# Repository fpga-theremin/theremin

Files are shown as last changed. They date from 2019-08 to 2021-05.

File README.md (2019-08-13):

# FPGA based theremin

Open source digital FPGA based theremin project.

Hardware design and build instructions can be found on [FPGA Theremin Project Page](https://fpga-theremin.github.io/theremin/)

[Theremin](https://en.wikipedia.org/wiki/Theremin) is an electronic musical instrument controlled without physical contact by the thereminist (performer).
It is named after the Westernized name of its Soviet inventor, Léon Theremin (Лев Термéн), who patented the device in 1928. 

FPGA Theremin project is attempt to build modern digital theremin with rich set of features.

## License 
FPGA Theremin is open source hardware and software project.

All hardware designed for this project 
is published under [TAPR Open Hardware License](https://www.tapr.org/TAPR_Open_Hardware_License_v1.0.txt)

All software (including both HDL and C/C++ code) 
is published under [GNU GENERAL PUBLIC LICENSE Version 2](https://www.gnu.org/licenses/old-licenses/gpl-2.0.txt)

## HDL sources

Modules are written in SystemVerilog.

Some of modules use Xilinx Series 7 specific hardware blocks.

HLD code for modules:

* [theremin_sensor](https://github.com/fpga-theremin/theremin/tree/master/fpga/ip_repo/theremin_ip/src/theremin_sensor) - double channel high precision frequency meter
* [encoders_board](https://github.com/fpga-theremin/theremin/tree/master/fpga/ip_repo/theremin_ip/src/encoders_board) - interfacing to 5 incremental encoders with buttons and one tact button
* [lcd_controller](https://github.com/fpga-theremin/theremin/tree/master/fpga/ip_repo/theremin_ip/src/lcd_controller) - LCD controller with RGB interface and DMA
* [audio_io](https://github.com/fpga-theremin/theremin/tree/master/fpga/ip_repo/theremin_ip/src/audio_io) - audio out 2 * stereo * 24bit * 48KHz I2S outputs and one stereo * 24bit * 48KHz I2S input
* [theremin_i2c](https://github.com/fpga-theremin/theremin/tree/master/fpga/ip_repo/theremin_ip/src/theremin_i2c) - I2C support
* [theremin_io](https://github.com/fpga-theremin/theremin/tree/master/fpga/ip_repo/theremin_ip/src/theremin_io) - Top Level Module combining all theremin peripherials

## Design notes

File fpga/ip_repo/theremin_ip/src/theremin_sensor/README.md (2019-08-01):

# Theremin Sensor module

Pitch and Volume oscillators produce 3.3V digital signal with frequency in range 200KHz..2MHz depending on inductor, duty cycle 50% (for implementation with flip-flop output).

Two input pins of FPGA board are used for receiving oscillator signals.

Frequency varies by ~7% depending on hand distance to antenna.

It's necessary to measure frequency of both signals with highest possible precision.

We can track changes of input signal and count number of clock cycles between its edges. Straightforward implementation in FPGA with counter may only provide limited resolution. 
200-300MHz is maximum possible resolution for simple counter based solution.

More sofisticated approach is required to get better precision.

There is a hardware deserielizer primitive in Xilinx Series 7 FPGAs.

ISERDESE2 in DDR mode allows to pack 8 sequencial samples of serial signal into parallel 8 bit output.

Max base frequency of ISERDESE2 on Cora Z7 device is 600MHz. In DDR mode, it samples input with 600MHz * 2 = 1.2GHz rate and provides new output each 600MHz / 4 = 150MHz clock cycle.

Parallel output of deserializer may be processed with lower frequency (150MHz) still providing 1.2GHz resolution.

This design still can be improved using Oversampling technique.

Measuring of the same signal several times with different delay and then averaging may allow to increase precision. Doubling of measures gives one additional bit of signal period data.

Simple oversampling solution used in this design uses 8 ISERDESE2 primitives with IDELAYE2 primitives on their inputs. Delay values are chosen to distribute subsamples evenly inside one 1.2GHz clock cycle.
It allows to get 64 bits (samples) of deserialized data each 150MHz clock cycle instead of 8 samples available with single ISERDESE2 deserializer.
Oversampling effectively gives 1.2GHz * 8 = 9.6GHz precision.

Once we have 64 bits of parallel data, we need to process them to measure intervals between sequential signal edges.

Steps of oversampling frequency measure processing:

* Deserialize input signal into 64 bits (samples) once per 150MHz cycle.
* Convert 64 bit values into single bit change flag and 6 bit changed bit number (0..63)
* Track changes to accumulate duration between signal edges - gives half period value (since last change, for either 0 or 1 signal value).
* Add two last half-period values to get full period value (number of 9.6GHz samples the same edge - positive or negative, new value is available after each input change).
* Filter measured period value using 4-stage IIR filter - to increase number of available bits

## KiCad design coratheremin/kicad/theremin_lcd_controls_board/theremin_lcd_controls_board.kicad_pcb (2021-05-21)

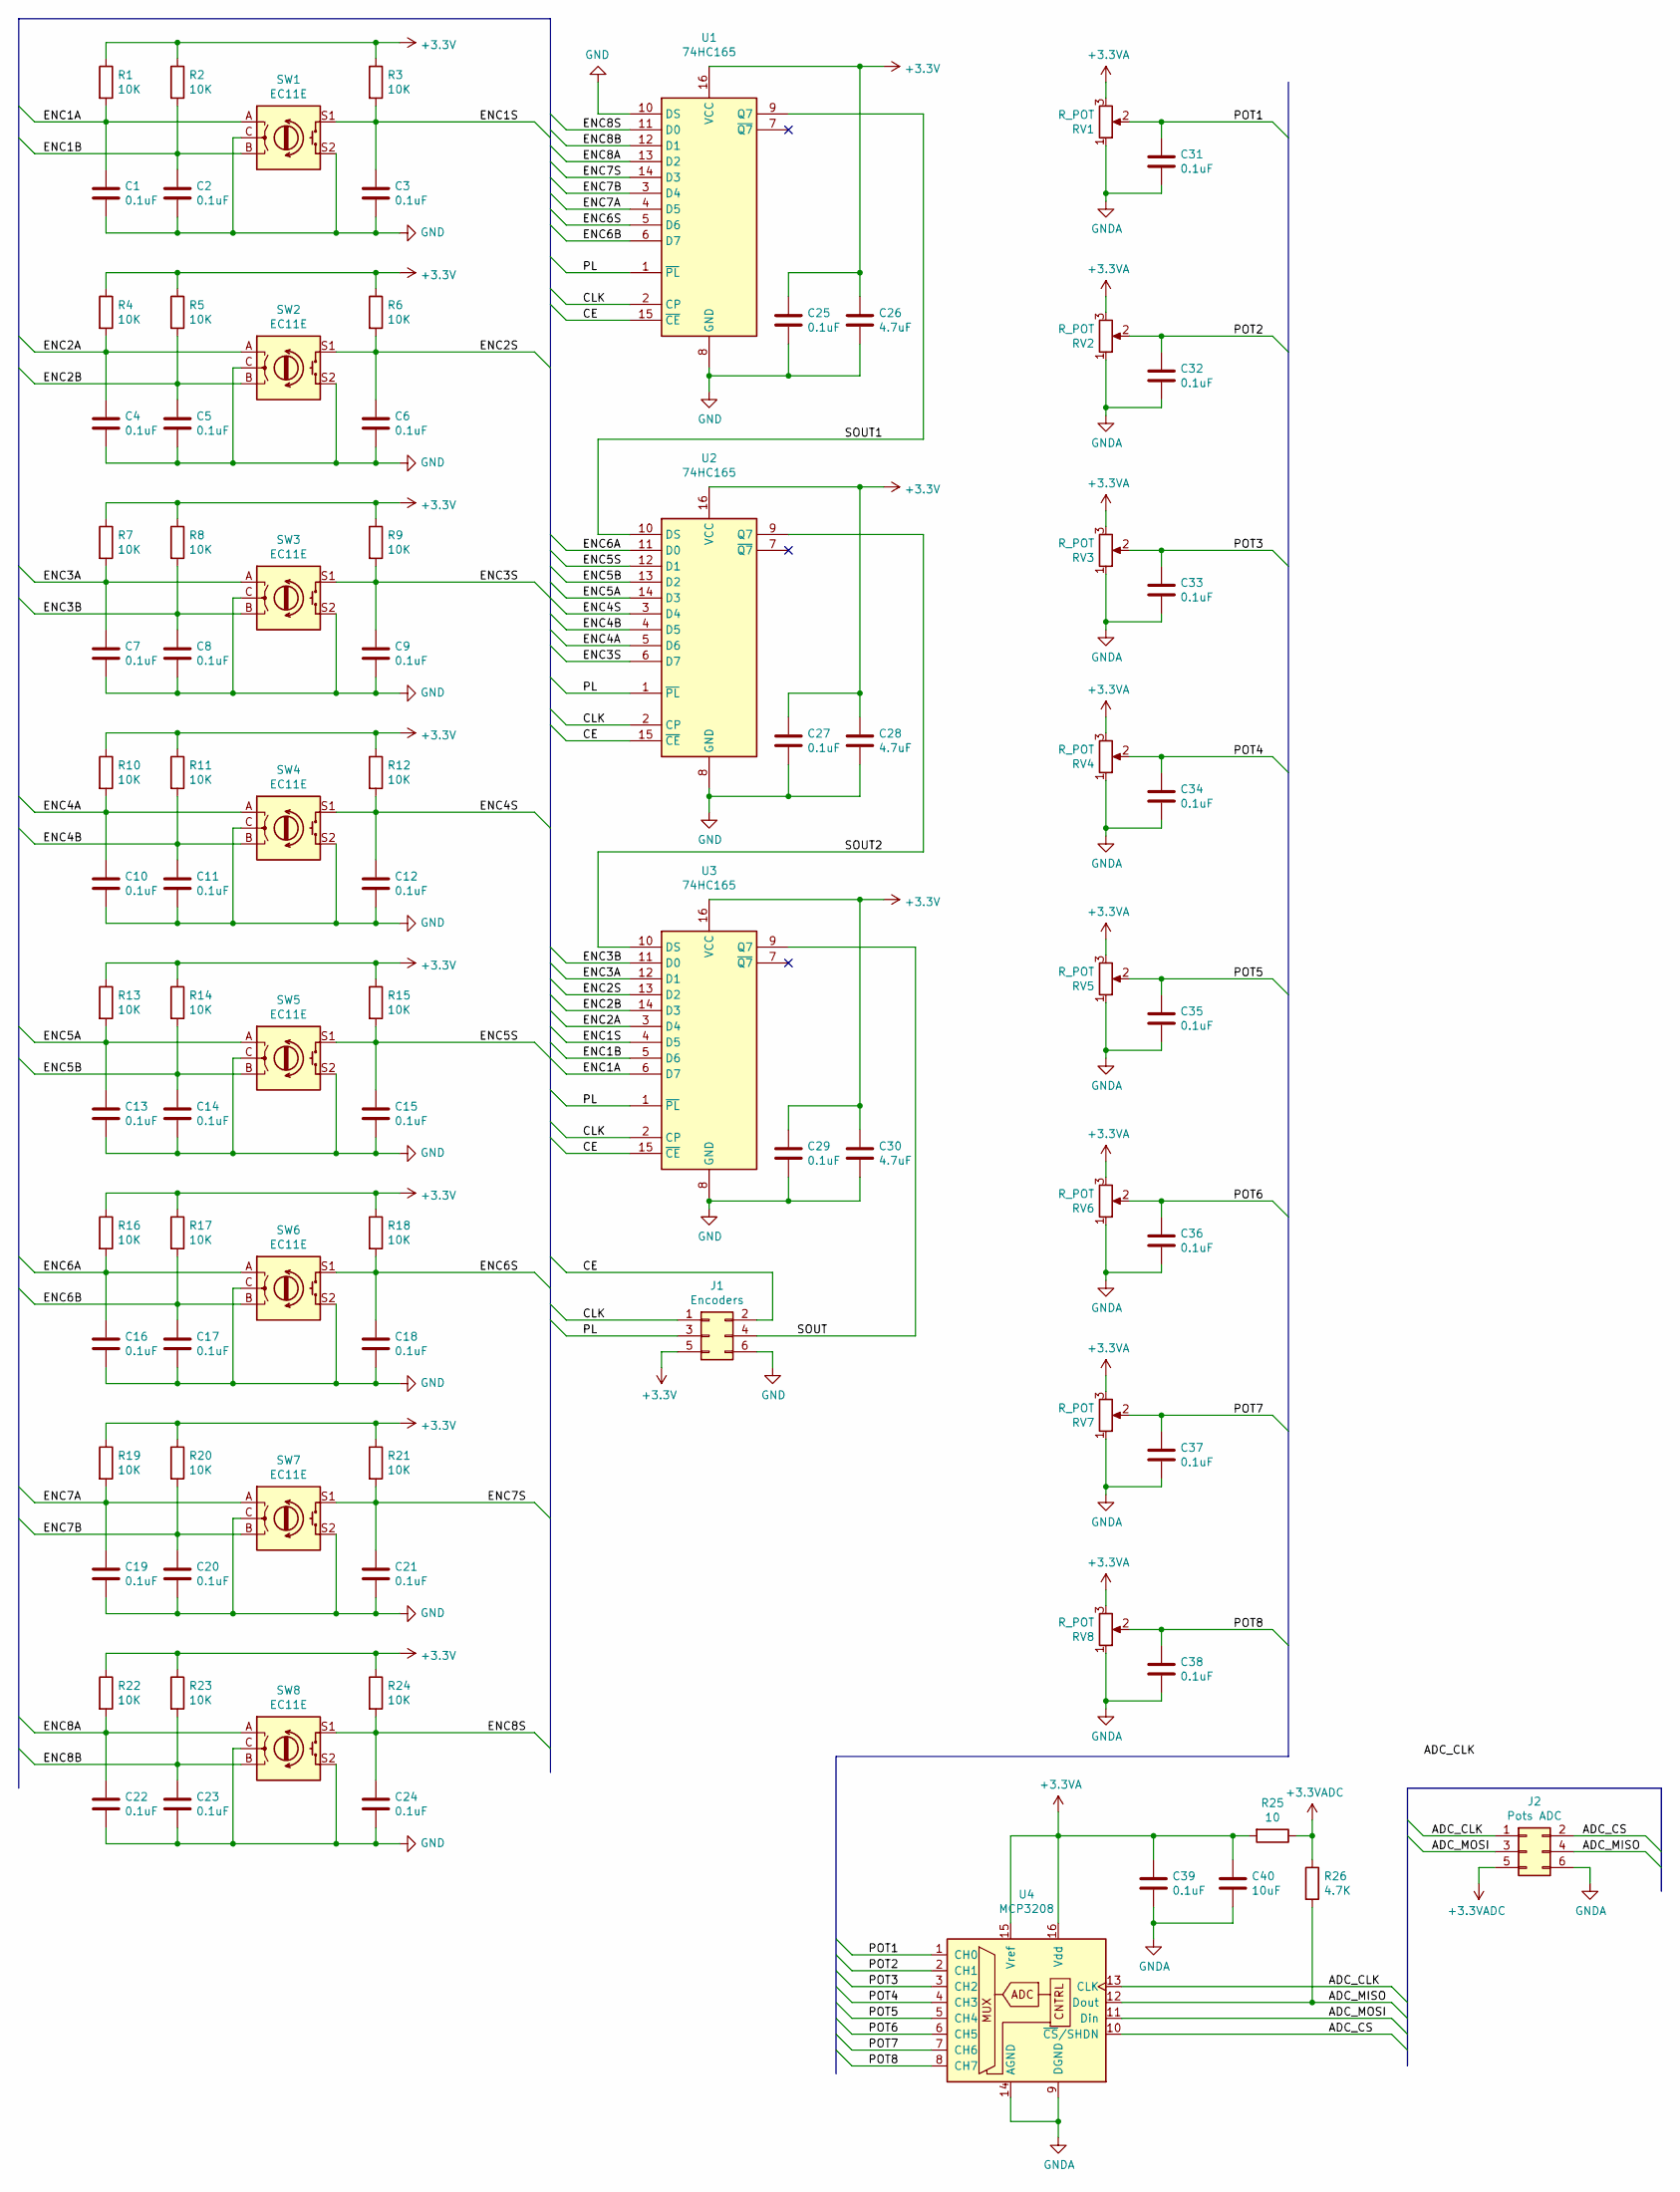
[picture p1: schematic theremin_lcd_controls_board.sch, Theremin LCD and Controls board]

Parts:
C1, C2, C3, C4, C5, C6, C7, C8, C9, C10, C11, C12, C13, C14, C15, C16, C17, C18, C19, C20, C21, C22, C23, C24, C25, C27, C29, C31, C32, C33, C34, C35, C36, C37, C38, C39: 0.1uF; C_0805_2012Metric
C26, C28, C30: 4.7uF; C_0805_2012Metric
C40: 10uF; C_0805_2012Metric
J1: Encoders; IDC-Header_2x03_P2.54mm_Vertical
J2: Pots ADC; IDC-Header_2x03_P2.54mm_Vertical
R1, R2, R3, R4, R5, R6, R7, R8, R9, R10, R11, R12, R13, R14, R15, R16, R17, R18, R19, R20, R21, R22, R23, R24: 10K; R_0805_2012Metric
R25: 10; R_0805_2012Metric
R26: 4.7K; R_0805_2012Metric
RV1, RV2, RV3, RV4, RV5, RV6, RV7, RV8: R_POT; Potentiometer_TT_P0915N
SW1, SW2, SW3, SW4, SW5, SW6, SW7, SW8: EC11E; RotaryEncoder_Alps_EC11E-Switch_Vertical_H20mm
U1, U2, U3: 74HC165; SO-16_3.9x9.9mm_P1.27mm
U4: MCP3208; SOIC-16_3.9x9.9mm_P1.27mm

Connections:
+3.3VA: C39.1, C40.1, R25.2, RV1.3, RV2.3, RV3.3, RV4.3, RV5.3, RV6.3, RV7.3, RV8.3, U4.15 (Vref), U4.16 (Vdd)
+3.3VADC: J2.5, R25.1, R26.1
+3V3: C25.1, C26.1, C27.1, C28.1, C29.1, C30.1, J1.5, R1.1, R2.1, R3.1, R4.1, R5.1, R6.1, R7.1, R8.1, R9.1, R10.1, R11.1, R12.1, R13.1, R14.1, R15.1, R16.1, R17.1, R18.1, R19.1, R20.1, R21.1, R22.1, R23.1, R24.1, U1.16 (VCC), U2.16 (VCC), U3.16 (VCC)
/ADC_CLK: J2.1, U4.13 (CLK)
/ADC_CS: J2.2, U4.10 (~CS~/SHDN)
/ADC_MISO: J2.4, R26.2, U4.12 (Dout)
/ADC_MOSI: J2.3, U4.11 (Din)
/CE: J1.2, U1.15 (~CE), U2.15 (~CE), U3.15 (~CE)
/CLK: J1.1, U1.2 (CP), U2.2 (CP), U3.2 (CP)
/ENC1A: C1.1, R1.2, SW1.A, U3.6 (D7)
/ENC1B: C2.1, R2.2, SW1.B, U3.5 (D6)
/ENC1S: C3.1, R3.2, SW1.S1, U3.4 (D5)
/ENC2A: C4.1, R4.2, SW2.A, U3.3 (D4)
/ENC2B: C5.1, R5.2, SW2.B, U3.14 (D3)
/ENC2S: C6.1, R6.2, SW2.S1, U3.13 (D2)
/ENC3A: C7.1, R7.2, SW3.A, U3.12 (D1)
/ENC3B: C8.1, R8.2, SW3.B, U3.11 (D0)
/ENC3S: C9.1, R9.2, SW3.S1, U2.6 (D7)
/ENC4A: C10.1, R10.2, SW4.A, U2.5 (D6)
/ENC4B: C11.1, R11.2, SW4.B, U2.4 (D5)
/ENC4S: C12.1, R12.2, SW4.S1, U2.3 (D4)
/ENC5A: C13.1, R13.2, SW5.A, U2.14 (D3)
/ENC5B: C14.1, R14.2, SW5.B, U2.13 (D2)
/ENC5S: C15.1, R15.2, SW5.S1, U2.12 (D1)
/ENC6A: C16.1, R16.2, SW6.A, U2.11 (D0)
/ENC6B: C17.1, R17.2, SW6.B, U1.6 (D7)
/ENC6S: C18.1, R18.2, SW6.S1, U1.5 (D6)
/ENC7A: C19.1, R19.2, SW7.A, U1.4 (D5)
/ENC7B: C20.1, R20.2, SW7.B, U1.3 (D4)
/ENC7S: C21.1, R21.2, SW7.S1, U1.14 (D3)
/ENC8A: C22.1, R22.2, SW8.A, U1.13 (D2)
/ENC8B: C23.1, R23.2, SW8.B, U1.12 (D1)
/ENC8S: C24.1, R24.2, SW8.S1, U1.11 (D0)
/PL: J1.3, U1.1 (~PL), U2.1 (~PL), U3.1 (~PL)
/POT1: C31.1, RV1.2, U4.1 (CH0)
/POT2: C32.1, RV2.2, U4.2 (CH1)
/POT3: C33.1, RV3.2, U4.3 (CH2)
/POT4: C34.1, RV4.2, U4.4 (CH3)
/POT5: C35.1, RV5.2, U4.5 (CH4)
/POT6: C36.1, RV6.2, U4.6 (CH5)
/POT7: C37.1, RV7.2, U4.7 (CH6)
/POT8: C38.1, RV8.2, U4.8 (CH7)
/SOUT: J1.4, U3.9 (Q7)
/SOUT1: U1.9 (Q7), U2.10 (DS)
/SOUT2: U2.9 (Q7), U3.10 (DS)
GND: C1.2, C2.2, C3.2, C4.2, C5.2, C6.2, C7.2, C8.2, C9.2, C10.2, C11.2, C12.2, C13.2, C14.2, C15.2, C16.2, C17.2, C18.2, C19.2, C20.2, C21.2, C22.2, C23.2, C24.2, C25.2, C26.2, C27.2, C28.2, C29.2, C30.2, J1.6, SW1.C, SW1.S2, SW2.C, SW2.S2, SW3.C, SW3.S2, SW4.C, SW4.S2, SW5.C, SW5.S2, SW6.C, SW6.S2, SW7.C, SW7.S2, SW8.C, SW8.S2, U1.8 (GND), U1.10 (DS), U2.8 (GND), U3.8 (GND)
GNDA: C31.2, C32.2, C33.2, C34.2, C35.2, C36.2, C37.2, C38.2, C39.2, C40.2, J2.6, RV1.1, RV2.1, RV3.1, RV4.1, RV5.1, RV6.1, RV7.1, RV8.1, U4.9 (DGND), U4.14 (AGND)

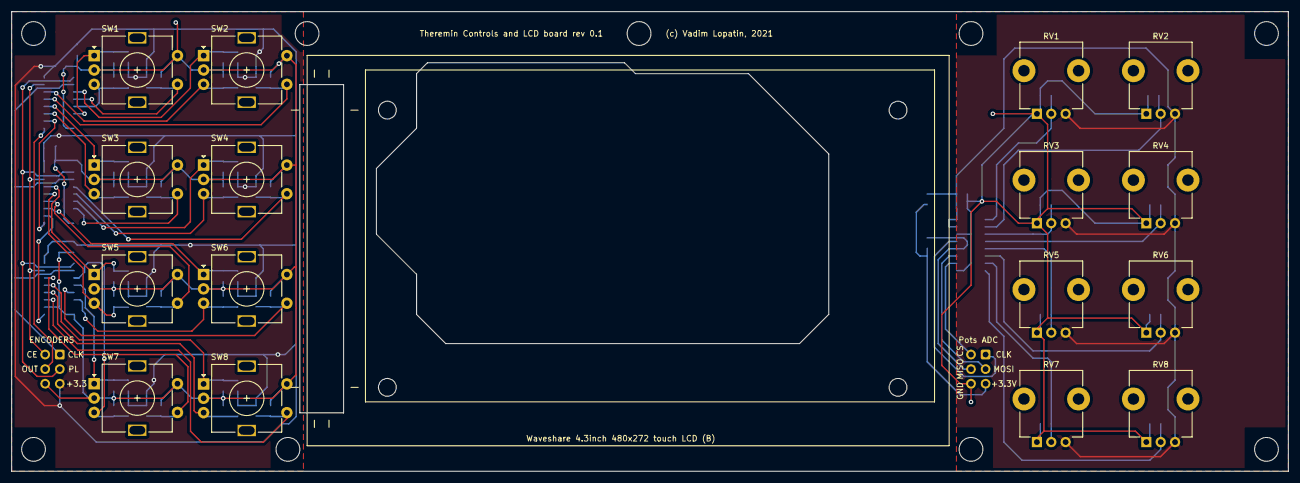
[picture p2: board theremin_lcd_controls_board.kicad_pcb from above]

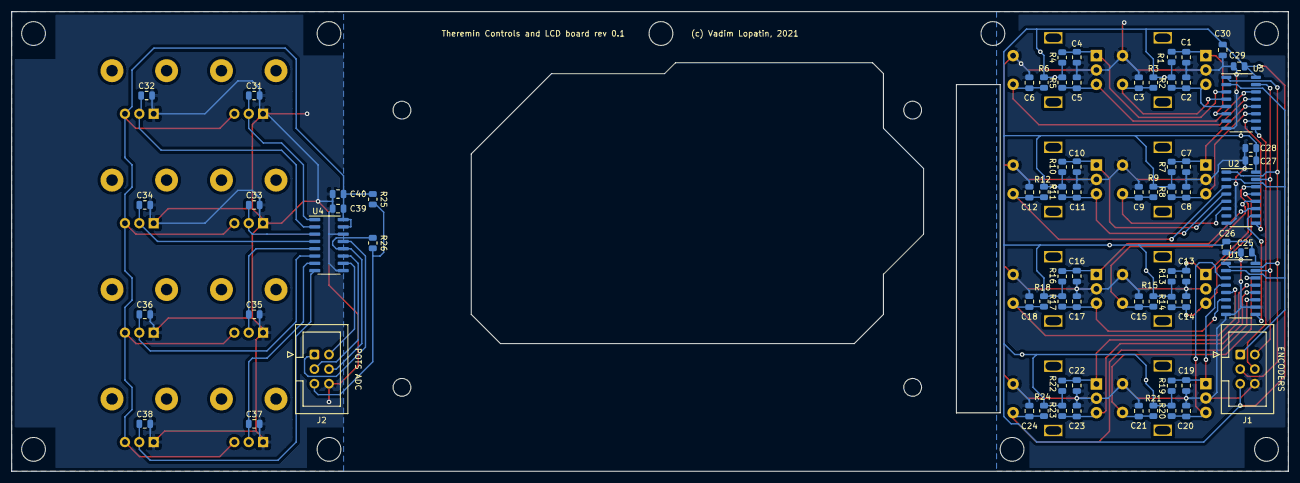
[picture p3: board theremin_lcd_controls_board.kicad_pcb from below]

Board: 2 copper layers, 222.2 x 80.0 mm, 88 parts (72 on the bottom side), 47 nets.

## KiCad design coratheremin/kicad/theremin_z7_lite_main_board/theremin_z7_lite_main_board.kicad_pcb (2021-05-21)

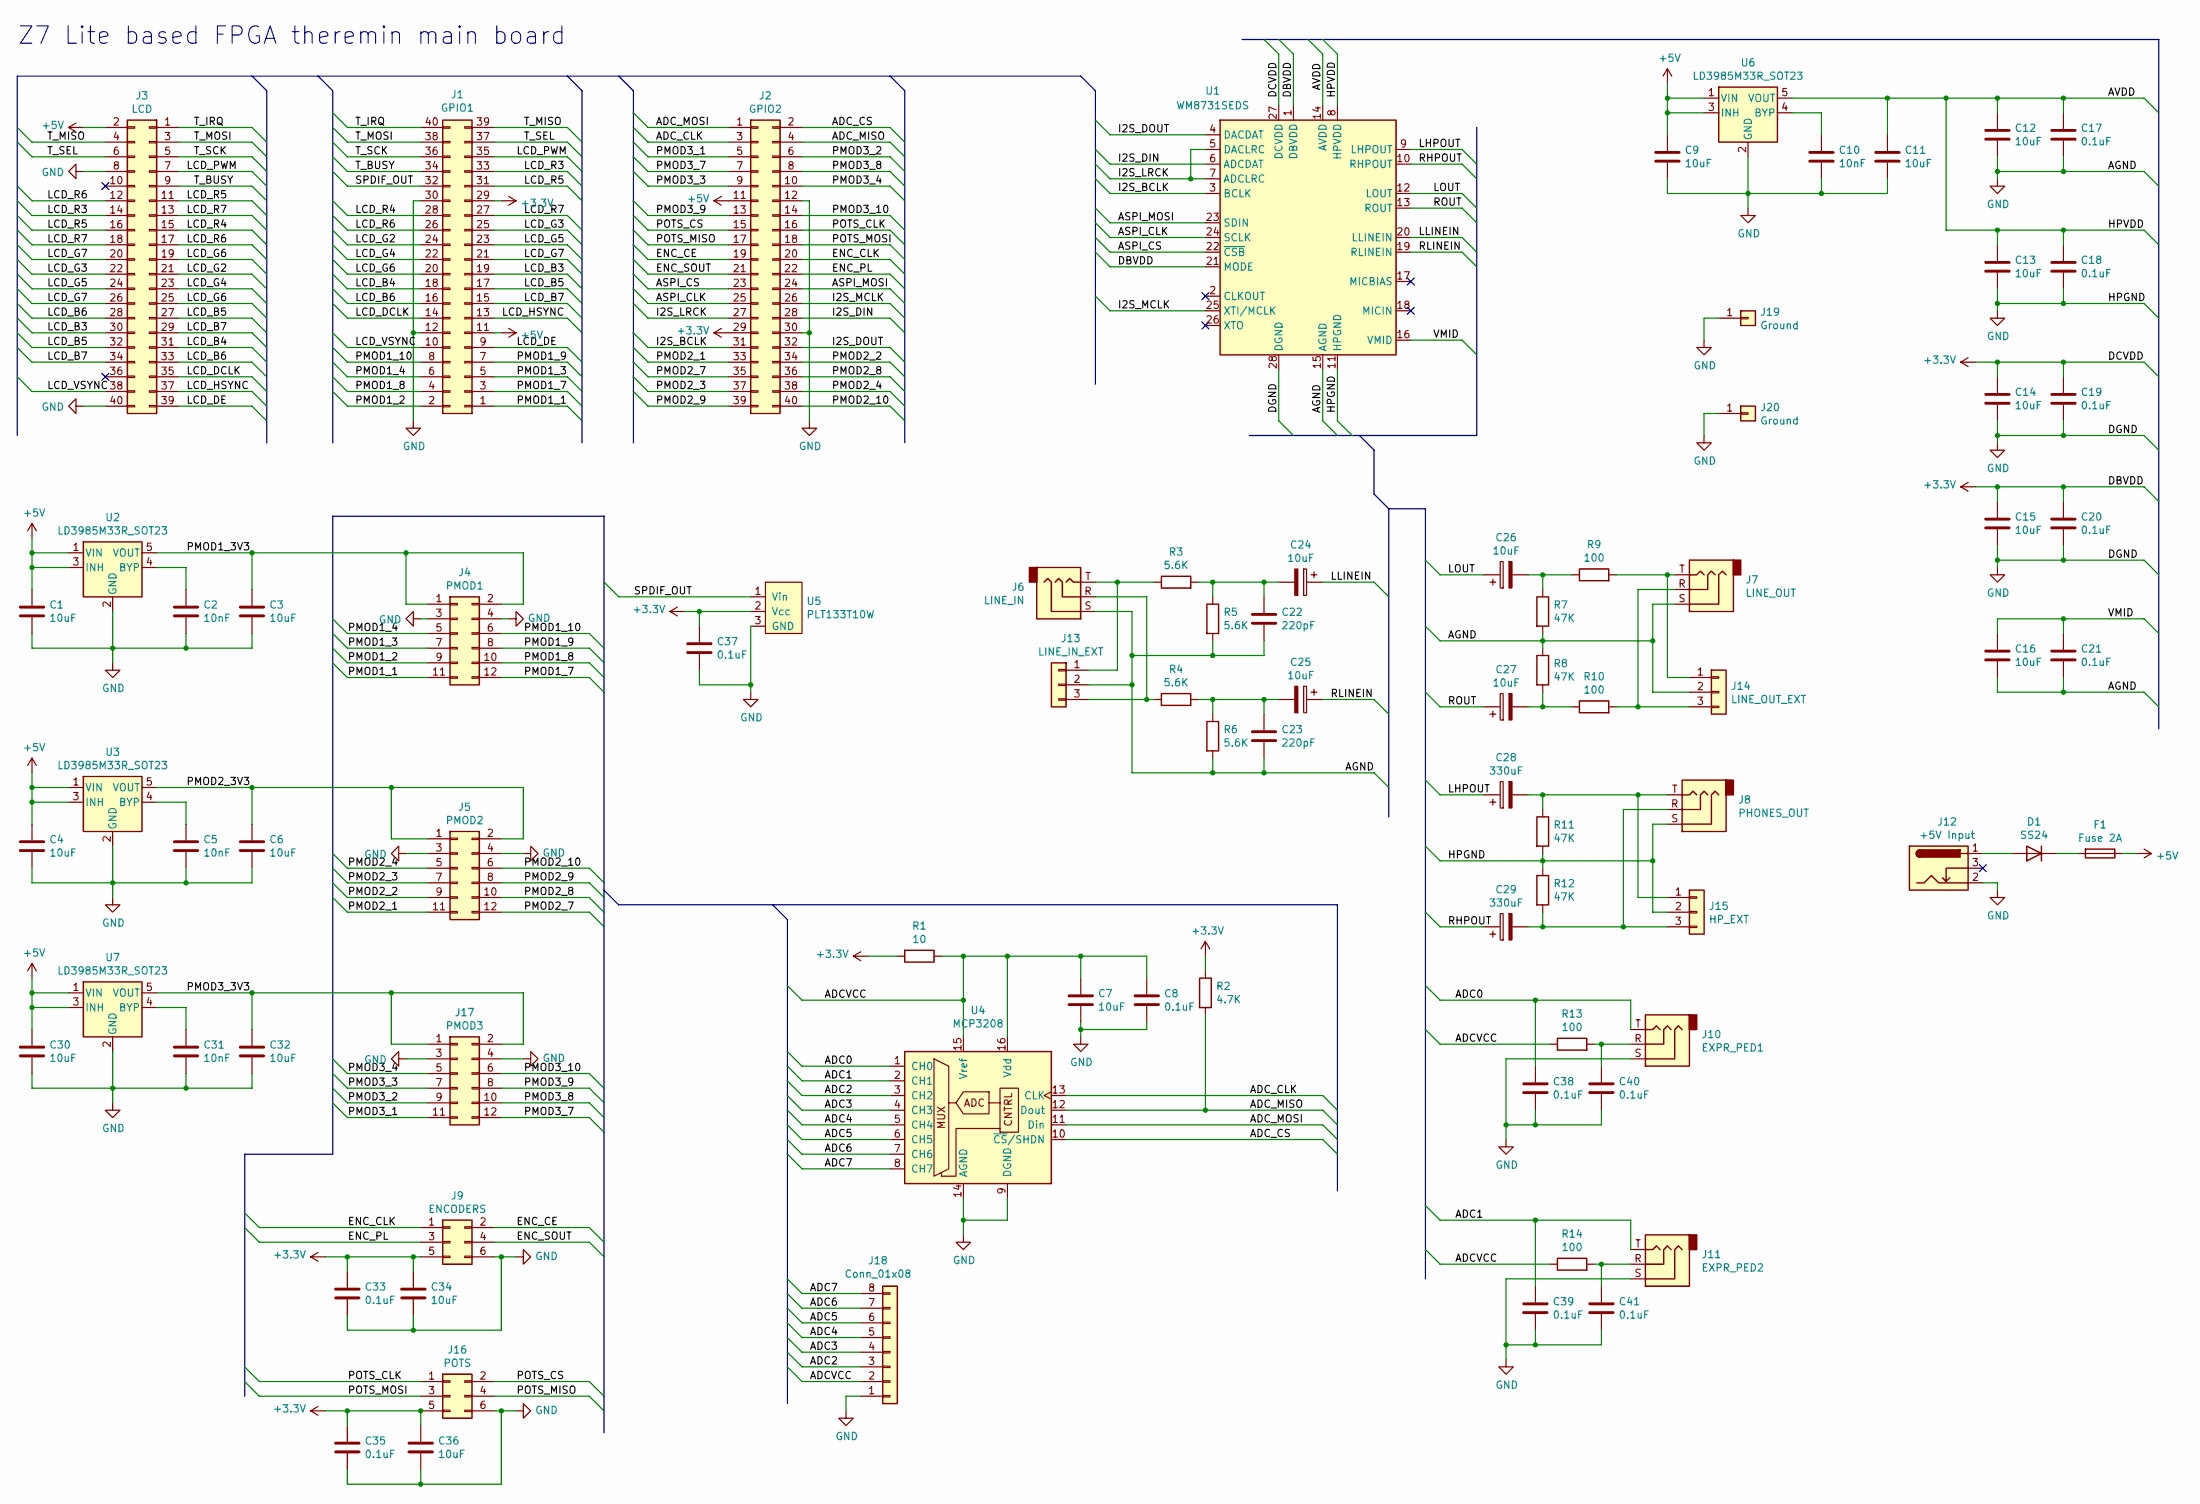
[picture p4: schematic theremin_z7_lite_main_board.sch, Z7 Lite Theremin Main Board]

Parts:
C1, C3, C4, C6, C7, C9, C11, C12, C13, C14, C15, C16, C30, C32, C34, C36: 10uF; C_0805_2012Metric
C2, C5, C10, C31: 10nF; C_0805_2012Metric
C8, C17, C18, C19, C20, C21, C33, C35, C37, C38, C39, C40, C41: 0.1uF; C_0805_2012Metric
C22, C23: 220pF; C_0805_2012Metric
C24, C25, C26, C27: 10uF; CP_Radial_D5.0mm_P2.00mm
C28, C29: 330uF; CP_Radial_D6.3mm_P2.50mm
D1: SS24; D_SMB
F1: Fuse 2A; Fuse_1206_3216Metric
J1: GPIO1; PinSocket_2x20_P2.54mm_Vertical
J2: GPIO2; PinSocket_2x20_P2.54mm_Vertical
J3: LCD; IDC-Header_2x20_P2.54mm_Vertical
J4: PMOD1; PinSocket_2x06_P2.54mm_Horizontal
J5: PMOD2; PinSocket_2x06_P2.54mm_Horizontal
J6: LINE_IN; Jack_6.35mm_ST_008G_04
J7: LINE_OUT; Jack_6.35mm_ST_008G_04
J8: PHONES_OUT; Jack_3.5mm_CUI_SJ1-3533NG_Horizontal
J9: ENCODERS; IDC-Header_2x03_P2.54mm_Vertical
J10: EXPR_PED1; Jack_6.35mm_ST_008G_04
J11: EXPR_PED2; Jack_6.35mm_ST_008G_04
J12: +5V Input; BarrelJack_Wuerth_6941xx301002
J13: LINE_IN_EXT; PinHeader_1x03_P2.54mm_Vertical
J14: LINE_OUT_EXT; PinHeader_1x03_P2.54mm_Vertical
J15: HP_EXT; PinHeader_1x03_P2.54mm_Vertical
J16: POTS; IDC-Header_2x03_P2.54mm_Vertical
J17: PMOD3; PinSocket_2x06_P2.54mm_Horizontal
J18: Conn_01x08; PinHeader_1x08_P2.54mm_Vertical
J19, J20: Ground; PinHeader_1x01_P2.54mm_Vertical
R1: 10; R_0805_2012Metric
R2: 4.7K; R_0805_2012Metric
R3, R4, R5, R6: 5.6K; R_0805_2012Metric
R7, R8, R11, R12: 47K; R_0805_2012Metric
R9, R10, R13, R14: 100; R_0805_2012Metric
U1: WM8731SEDS; SSOP-28_5.3x10.2mm_P0.65mm
U2, U3, U6, U7: LD3985M33R_SOT23; SOT-23-5
U4: MCP3208; SOIC-16_3.9x9.9mm_P1.27mm
U5: PLT133T10W

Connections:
+3V3: C14.1, C15.1, C19.1, C20.1, C33.1, C34.1, C35.1, C36.1, C37.1, J1.29, J2.29, J9.5, J16.5, R1.2, R2.1, U1.1 (DBVDD), U1.21 (MODE), U1.27 (DCVDD), U5.2 (Vcc)
+5V: C1.1, C4.1, C9.1, C30.1, F1.1, J1.11, J2.11, J3.2, U2.1 (VIN), U2.3 (INH), U3.1 (VIN), U3.3 (INH), U6.1 (VIN), U6.3 (INH), U7.1 (VIN), U7.3 (INH)
/ADC0: C38.1, J10.T, U4.1 (CH0)
/ADC1: C39.1, J11.T, U4.2 (CH1)
/ADC2: J18.3, U4.3 (CH2)
/ADC3: J18.4, U4.4 (CH3)
/ADC4: J18.5, U4.5 (CH4)
/ADC5: J18.6, U4.6 (CH5)
/ADC6: J18.7, U4.7 (CH6)
/ADC7: J18.8, U4.8 (CH7)
/ADCVCC: C7.1, C8.1, J18.2, R1.1, R13.1, R14.1, U4.15 (Vref), U4.16 (Vdd)
/ADC_CLK: J2.3, U4.13 (CLK)
/ADC_CS: J2.2, U4.10 (~CS~/SHDN)
/ADC_MISO: J2.4, R2.2, U4.12 (Dout)
/ADC_MOSI: J2.1, U4.11 (Din)
/ASPI_CLK: J2.25, U1.24 (SCLK)
/ASPI_CS: J2.23, U1.22 (~CSB)
/ASPI_MOSI: J2.24, U1.23 (SDIN)
/AVDD: C11.1, C12.1, C13.1, C17.1, C18.1, U1.8 (HPVDD), U1.14 (AVDD), U6.5 (VOUT)
/ENC_CE: J2.19, J9.2
/ENC_CLK: J2.20, J9.1
/ENC_PL: J2.22, J9.3
/ENC_SOUT: J2.21, J9.4
/I2S_BCLK: J2.31, U1.3 (BCLK)
/I2S_DIN: J2.28, U1.6 (ADCDAT)
/I2S_DOUT: J2.32, U1.4 (DACDAT)
/I2S_LRCK: J2.27, U1.5 (DACLRC), U1.7 (ADCLRC)
/I2S_MCLK: J2.26, U1.25 (XTI/MCLK)
/LCD_B3: J1.19, J3.30
/LCD_B4: J1.18, J3.31
/LCD_B5: J1.17, J3.27, J3.32
/LCD_B6: J1.16, J3.28, J3.33
/LCD_B7: J1.15, J3.29, J3.34
/LCD_DCLK: J1.14, J3.35
/LCD_DE: J1.9, J3.39
/LCD_G2: J1.24, J3.21
/LCD_G3: J1.25, J3.22
/LCD_G4: J1.22, J3.23
/LCD_G5: J1.23, J3.24
/LCD_G6: J1.20, J3.19, J3.25
/LCD_G7: J1.21, J3.20, J3.26
/LCD_HSYNC: J1.13, J3.37
/LCD_PWM: J1.35, J3.7
/LCD_R3: J1.33, J3.14
/LCD_R4: J1.28, J3.15
/LCD_R5: J1.31, J3.11, J3.16
/LCD_R6: J1.26, J3.12, J3.17
/LCD_R7: J1.27, J3.13, J3.18
/LCD_VSYNC: J1.10, J3.38
/LHPOUT: C28.1, U1.9 (LHPOUT)
/LLINEIN: C24.1, U1.20 (LLINEIN)
/LOUT: C26.1, U1.12 (LOUT)
/PMOD1_1: J1.1, J4.11
/PMOD1_2: J1.2, J4.9
/PMOD1_3: J1.5, J4.7
/PMOD1_3V3: C3.1, J4.1, J4.2, U2.5 (VOUT)
/PMOD1_4: J1.6, J4.5
/PMOD1_7: J1.3, J4.12
/PMOD1_8: J1.4, J4.10
/PMOD1_9: J1.7, J4.8
/PMOD1_10: J1.8, J4.6
/PMOD2_1: J2.33, J5.11
/PMOD2_2: J2.34, J5.9
/PMOD2_3: J2.37, J5.7
/PMOD2_3V3: C6.1, J5.1, J5.2, U3.5 (VOUT)
/PMOD2_4: J2.38, J5.5
/PMOD2_7: J2.35, J5.12
/PMOD2_8: J2.36, J5.10
/PMOD2_9: J2.39, J5.8
/PMOD2_10: J2.40, J5.6
/PMOD3_1: J2.5, J17.11
/PMOD3_2: J2.6, J17.9
/PMOD3_3: J2.9, J17.7
/PMOD3_3V3: C32.1, J17.1, J17.2, U7.5 (VOUT)
/PMOD3_4: J2.10, J17.5
/PMOD3_7: J2.7, J17.12
/PMOD3_8: J2.8, J17.10
/PMOD3_9: J2.13, J17.8
/PMOD3_10: J2.14, J17.6
/POTS_CLK: J2.16, J16.1
/POTS_CS: J2.15, J16.2
/POTS_MISO: J2.17, J16.4
/POTS_MOSI: J2.18, J16.3
/RHPOUT: C29.1, U1.10 (RHPOUT)
/RLINEIN: C25.1, U1.19 (RLINEIN)
/ROUT: C27.1, U1.13 (ROUT)
/SPDIF_OUT: J1.32, U5.1 (Vin)
/T_BUSY: J1.34, J3.9
/T_IRQ: J1.40, J3.1
/T_MISO: J1.39, J3.4
/T_MOSI: J1.38, J3.3
/T_SCK: J1.36, J3.5
/T_SEL: J1.37, J3.6
/VMID: C16.1, C21.1, U1.16 (VMID)
GND: C1.2, C2.2, C3.2, C4.2, C5.2, C6.2, C7.2, C8.2, C9.2, C10.2, C11.2, C12.2, C13.2, C14.2, C15.2, C16.2, C17.2, C18.2, C19.2, C20.2, C21.2, C22.2, C23.2, C30.2, C31.2, C32.2, C33.2, C34.2, C35.2, C36.2, C37.2, C38.2, C39.2, C40.2, C41.2, J1.12, J1.30, J2.12, J2.30, J3.8, J3.40, J4.3, J4.4, J5.3, J5.4, J6.S, J7.S, J8.S, J9.6, J10.S, J11.S, J12.2, J13.2, J14.2, J15.2, J16.6, J17.3, J17.4, J18.1, J19.1, J20.1, R5.2, R6.2, R7.2, R8.1, R11.2, R12.1, U1.11 (HPGND), U1.15 (AGND), U1.28 (DGND), U2.2 (GND), U3.2 (GND), U4.9 (DGND), U4.14 (AGND), U5.3 (GND), U6.2 (GND), U7.2 (GND)
unnamed: C2.1, U2.4 (BYP)
unnamed: C5.1, U3.4 (BYP)
unnamed: C10.1, U6.4 (BYP)
unnamed: C22.1, C24.2, R3.2, R5.1
unnamed: C23.1, C25.2, R4.2, R6.1
unnamed: C26.2, R7.1, R9.1
unnamed: C27.2, R8.2, R10.1
unnamed: C28.2, J8.T, J15.1, R11.1
unnamed: C29.2, J8.R, J15.3, R12.2
unnamed: C31.1, U7.4 (BYP)
unnamed: C40.1, J10.R, R13.2
unnamed: C41.1, J11.R, R14.2
unnamed: D1.1 (K), F1.2
unnamed: D1.2 (A), J12.1
unnamed: J6.T, J13.1, R3.1
unnamed: J6.R, J13.3, R4.1
unnamed: J7.T, J14.1, R9.2
unnamed: J7.R, J14.3, R10.2

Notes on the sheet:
Z7 Lite based FPGA theremin main board

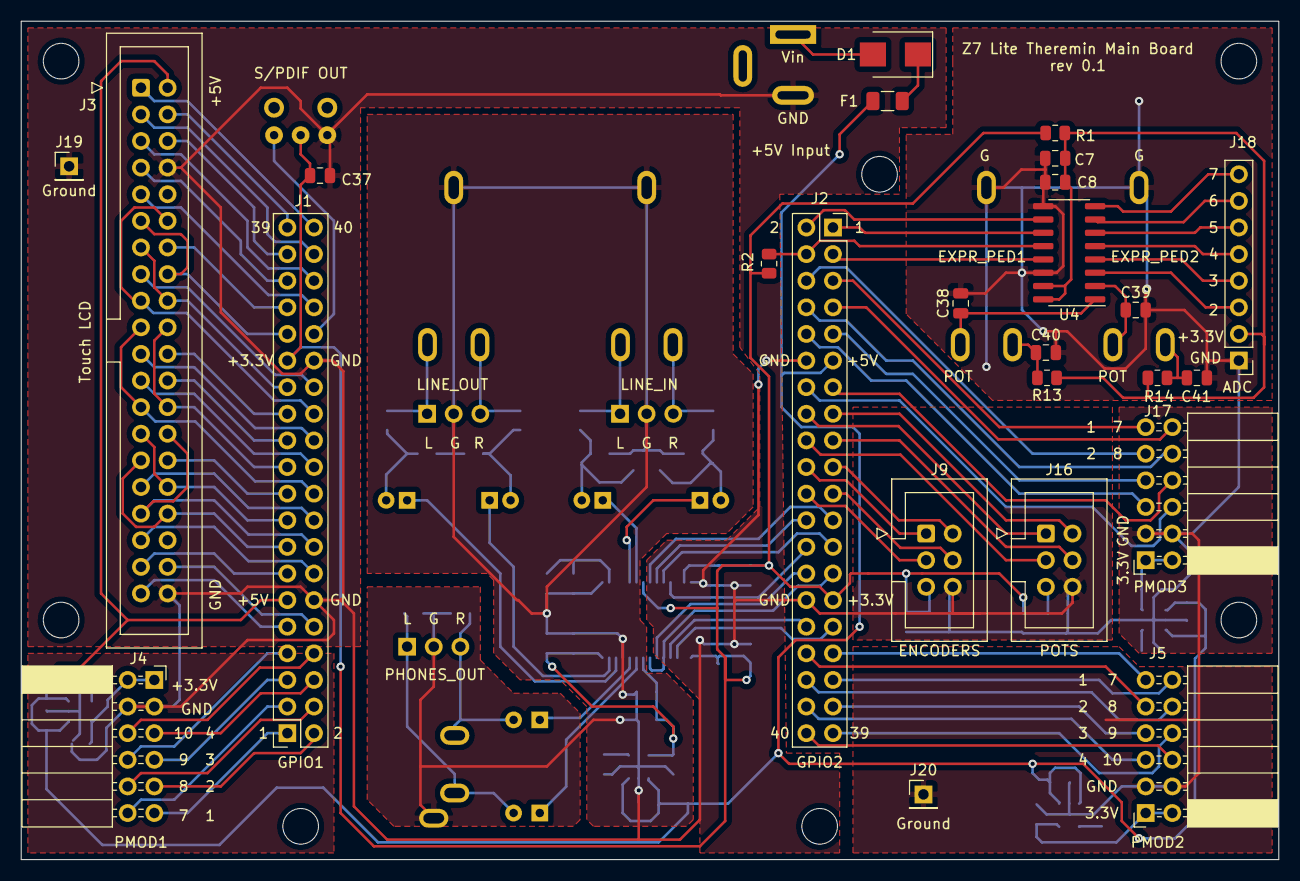
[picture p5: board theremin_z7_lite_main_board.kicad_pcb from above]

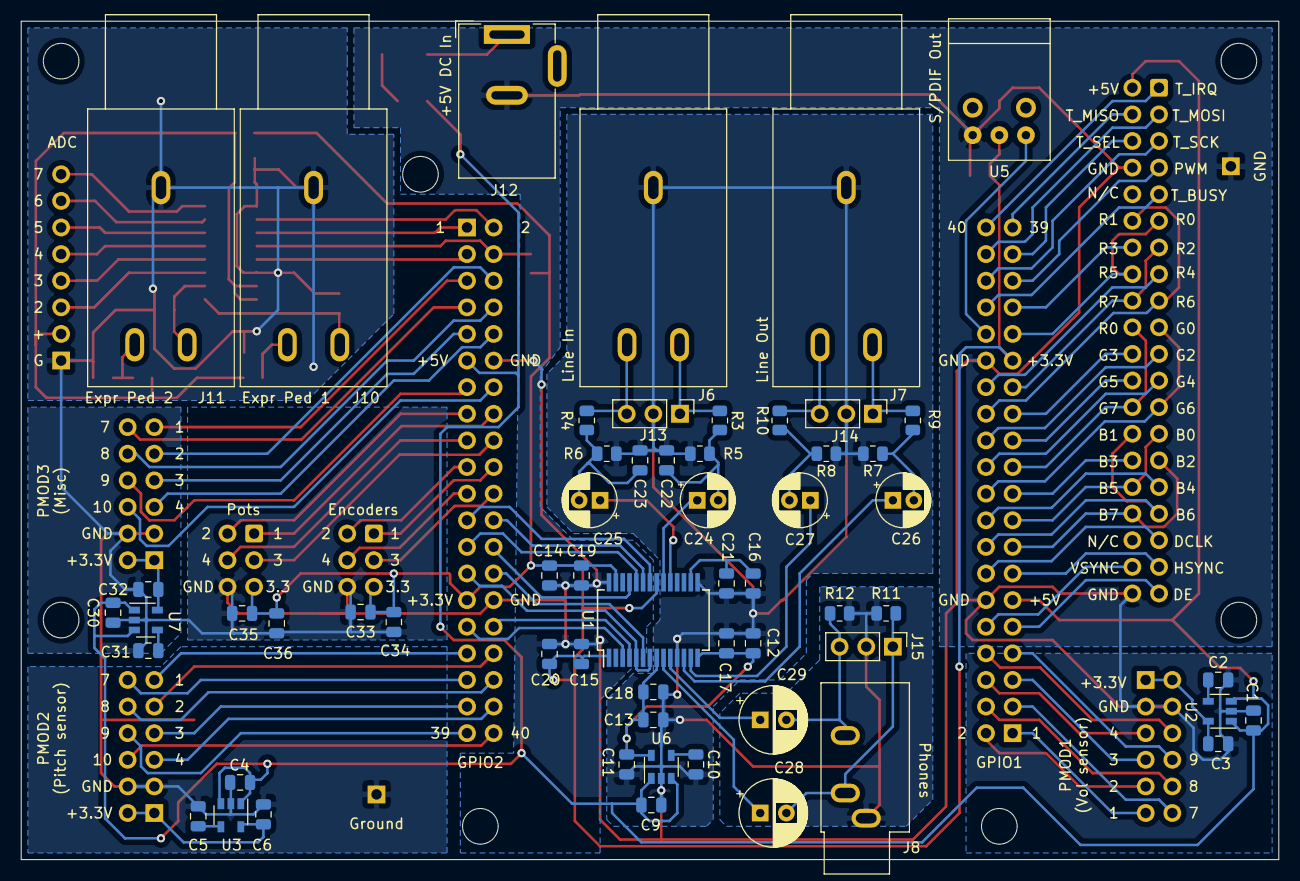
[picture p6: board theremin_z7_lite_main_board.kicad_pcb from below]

Board: 2 copper layers, 120.0 x 80.0 mm, 84 parts (59 on the bottom side), 113 nets.

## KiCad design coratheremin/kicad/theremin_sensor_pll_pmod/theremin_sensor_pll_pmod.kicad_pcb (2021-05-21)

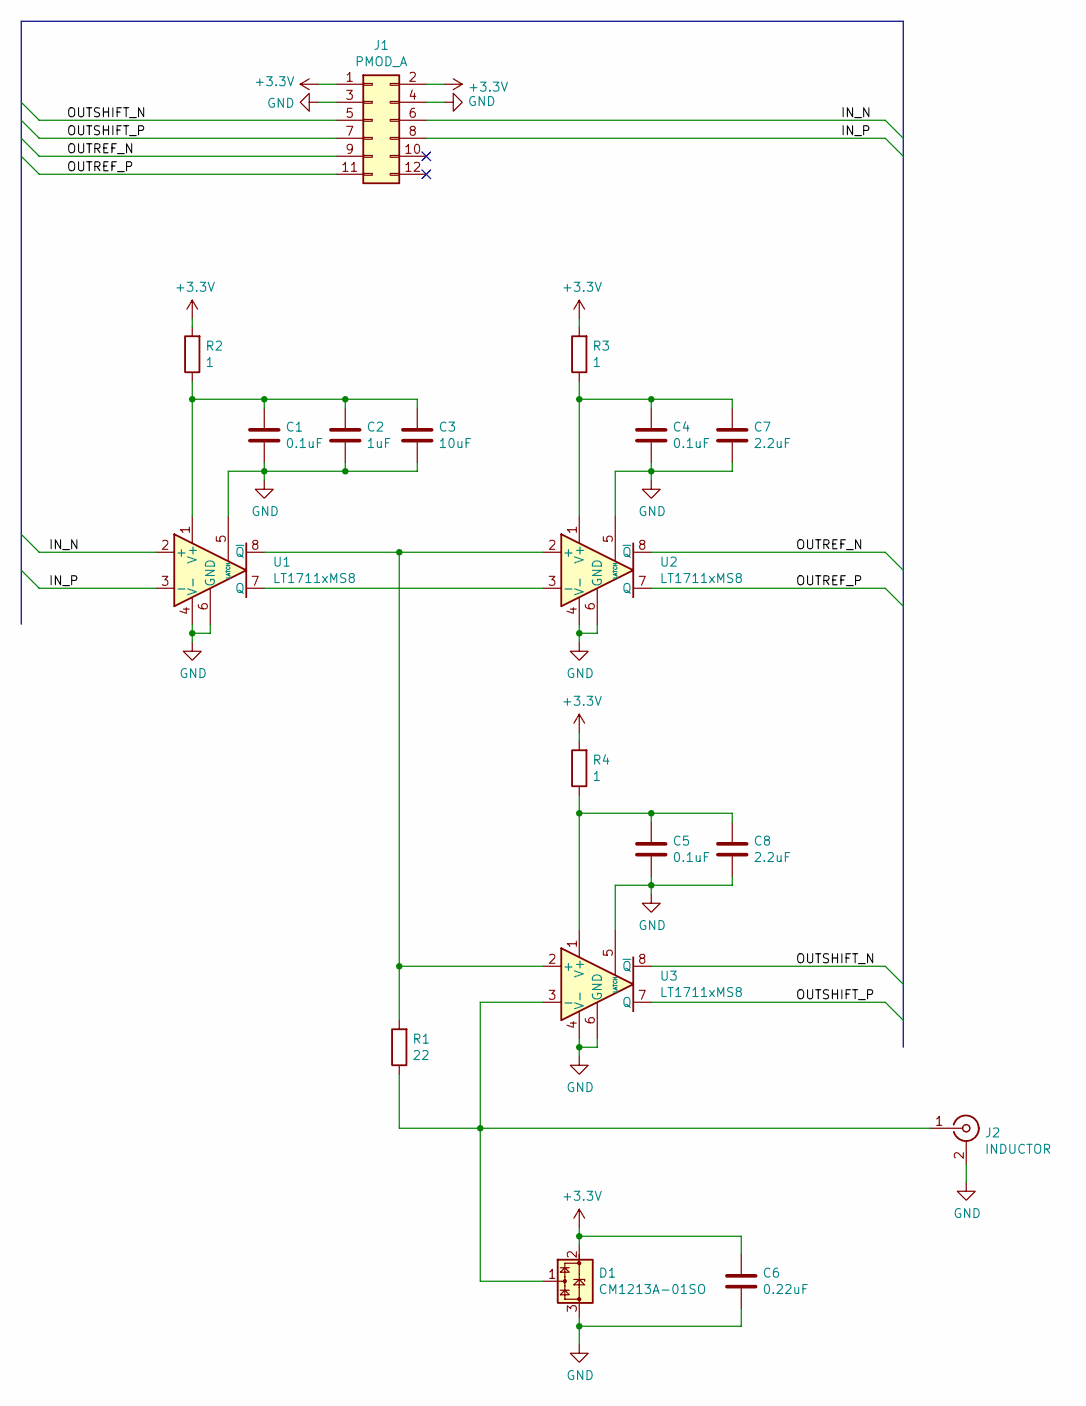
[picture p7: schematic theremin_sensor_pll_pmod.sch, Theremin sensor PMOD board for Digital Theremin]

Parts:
C1, C4, C5: 0.1uF; C_0805_2012Metric_Pad1.18x1.45mm_HandSolder
C2: 1uF; C_0805_2012Metric_Pad1.18x1.45mm_HandSolder
C3: 10uF; C_0805_2012Metric_Pad1.18x1.45mm_HandSolder
C6: 0.22uF; C_0805_2012Metric_Pad1.18x1.45mm_HandSolder
C7, C8: 2.2uF; C_0805_2012Metric_Pad1.18x1.45mm_HandSolder
D1: CM1213A-01SO; SOT-23
J1: PMOD_A; PinHeader_2x06_P2.54mm_Horizontal
J2: INDUCTOR; SMA_Wurth_60312002114503_Vertical
R1: 22; R_0805_2012Metric
R2, R3, R4: 1; R_0805_2012Metric
U1, U2, U3: LT1711xMS8; MSOP-8_3x3mm_P0.65mm

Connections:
+3V3: C6.1, D1.2 (VP), J1.1, J1.2, R2.2, R3.2, R4.2
/IN_N: J1.6, U1.2 (+)
/IN_P: J1.8, U1.3 (-)
/OUTREF_N: J1.9, U2.8 (~Q)
/OUTREF_P: J1.11, U2.7 (Q)
/OUTSHIFT_N: J1.5, U3.8 (~Q)
/OUTSHIFT_P: J1.7, U3.7 (Q)
GND: C1.2, C2.2, C3.2, C4.2, C5.2, C6.2, C7.2, C8.2, D1.3 (VN), J1.3, J1.4, J2.2 (Ext), U1.4 (V-), U1.5 (LATCH), U1.6 (GND), U2.4 (V-), U2.5 (LATCH), U2.6 (GND), U3.4 (V-), U3.5 (LATCH), U3.6 (GND)
unnamed: C1.1, C2.1, C3.1, R2.1, U1.1 (V+)
unnamed: C4.1, C7.1, R3.1, U2.1 (V+)
unnamed: C5.1, C8.1, R4.1, U3.1 (V+)
unnamed: D1.1 (CH1), J2.1 (In), R1.1, U3.3 (-)
unnamed: R1.2, U1.8 (~Q), U2.2 (+), U3.2 (+)
unnamed: U1.7 (Q), U2.3 (-)

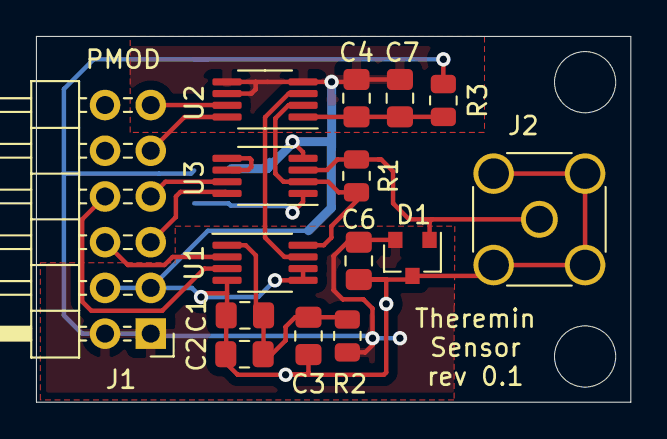
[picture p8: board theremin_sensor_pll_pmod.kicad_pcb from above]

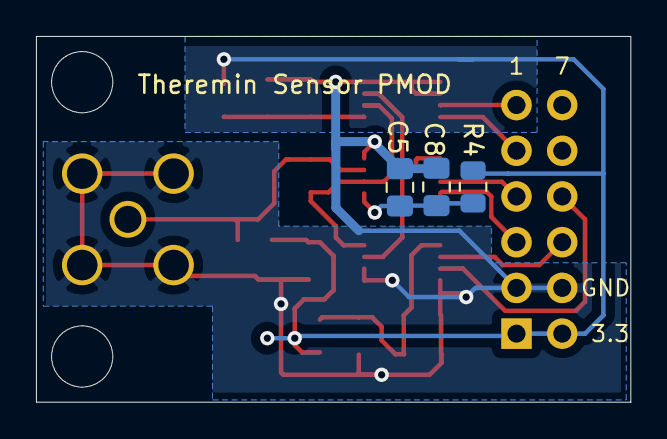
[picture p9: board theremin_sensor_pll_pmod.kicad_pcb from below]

Board: 2 copper layers, 33.0 x 20.3 mm, 18 parts (3 on the bottom side), 14 nets.

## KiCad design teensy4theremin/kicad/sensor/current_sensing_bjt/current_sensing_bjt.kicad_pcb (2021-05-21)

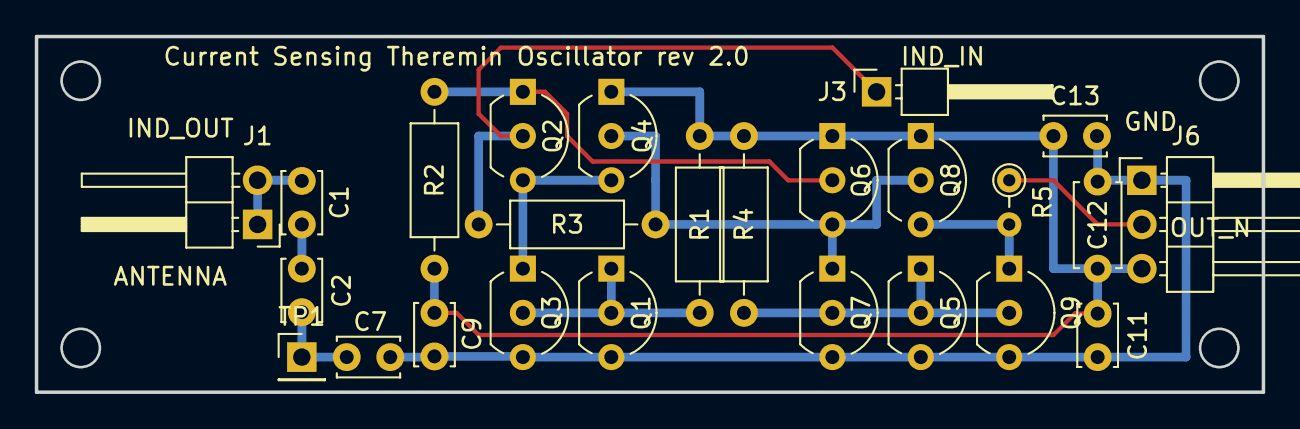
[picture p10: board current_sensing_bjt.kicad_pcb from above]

Board: 2 copper layers, 70.5 x 20.4 mm, 25 parts (0 on the bottom side), 13 nets.

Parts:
C1, C2: 1pF; C_Disc_D3.4mm_W2.1mm_P2.50mm
C7: 1000pF; C_Disc_D3.4mm_W2.1mm_P2.50mm
C9, C11, C13: 0.1uF; C_Disc_D3.4mm_W2.1mm_P2.50mm
C12: 10uF; C_Disc_D4.7mm_W2.5mm_P5.00mm
J1: ANTENNA; PinHeader_1x02_P2.54mm_Horizontal
J3: INDUCTOR_IN; PinHeader_1x01_P2.54mm_Horizontal
J6: OSC; PinHeader_1x03_P2.54mm_Horizontal
Q1, Q2, Q3, Q4, Q5, Q6, Q7, Q8, Q9: BC549; TO-92_Inline_Wide
R1, R2: 4.7K; R_Axial_DIN0207_L6.3mm_D2.5mm_P10.16mm_Horizontal
R3: 47; R_Axial_DIN0207_L6.3mm_D2.5mm_P10.16mm_Horizontal
R4: 680; R_Axial_DIN0207_L6.3mm_D2.5mm_P10.16mm_Horizontal
R5: 100; R_Axial_DIN0204_L3.6mm_D1.6mm_P2.54mm_Vertical
TP1: Antenna Voltage Swing; PinHeader_1x01_P2.54mm_Vertical

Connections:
/OUT: J6.2, R5.1
GND: C7.2, C9.2, C11.2, C12.2, C13.2, J6.1, Q1.3, Q3.3, Q5.3, Q7.3, Q9.3
unnamed: C1.1, C2.2
unnamed: C1.2, J1.1, J1.2
unnamed: C2.1, C7.1, TP1.1
unnamed: J3.1, Q2.2, R3.2
unnamed: Q1.1, Q1.2, Q3.2, R1.2
unnamed: Q2.1, Q6.2, R2.2
unnamed: Q2.3, Q3.1, Q4.3
unnamed: Q4.2, Q6.3, Q7.1, Q8.2, R3.1
unnamed: Q5.1, Q5.2, Q7.2, Q9.2, R4.2
unnamed: Q8.3, Q9.1, R5.2
VCC: C9.1, C11.1, C12.1, C13.1, J6.3, Q4.1, Q6.1, Q8.1, R1.1, R2.1, R4.1

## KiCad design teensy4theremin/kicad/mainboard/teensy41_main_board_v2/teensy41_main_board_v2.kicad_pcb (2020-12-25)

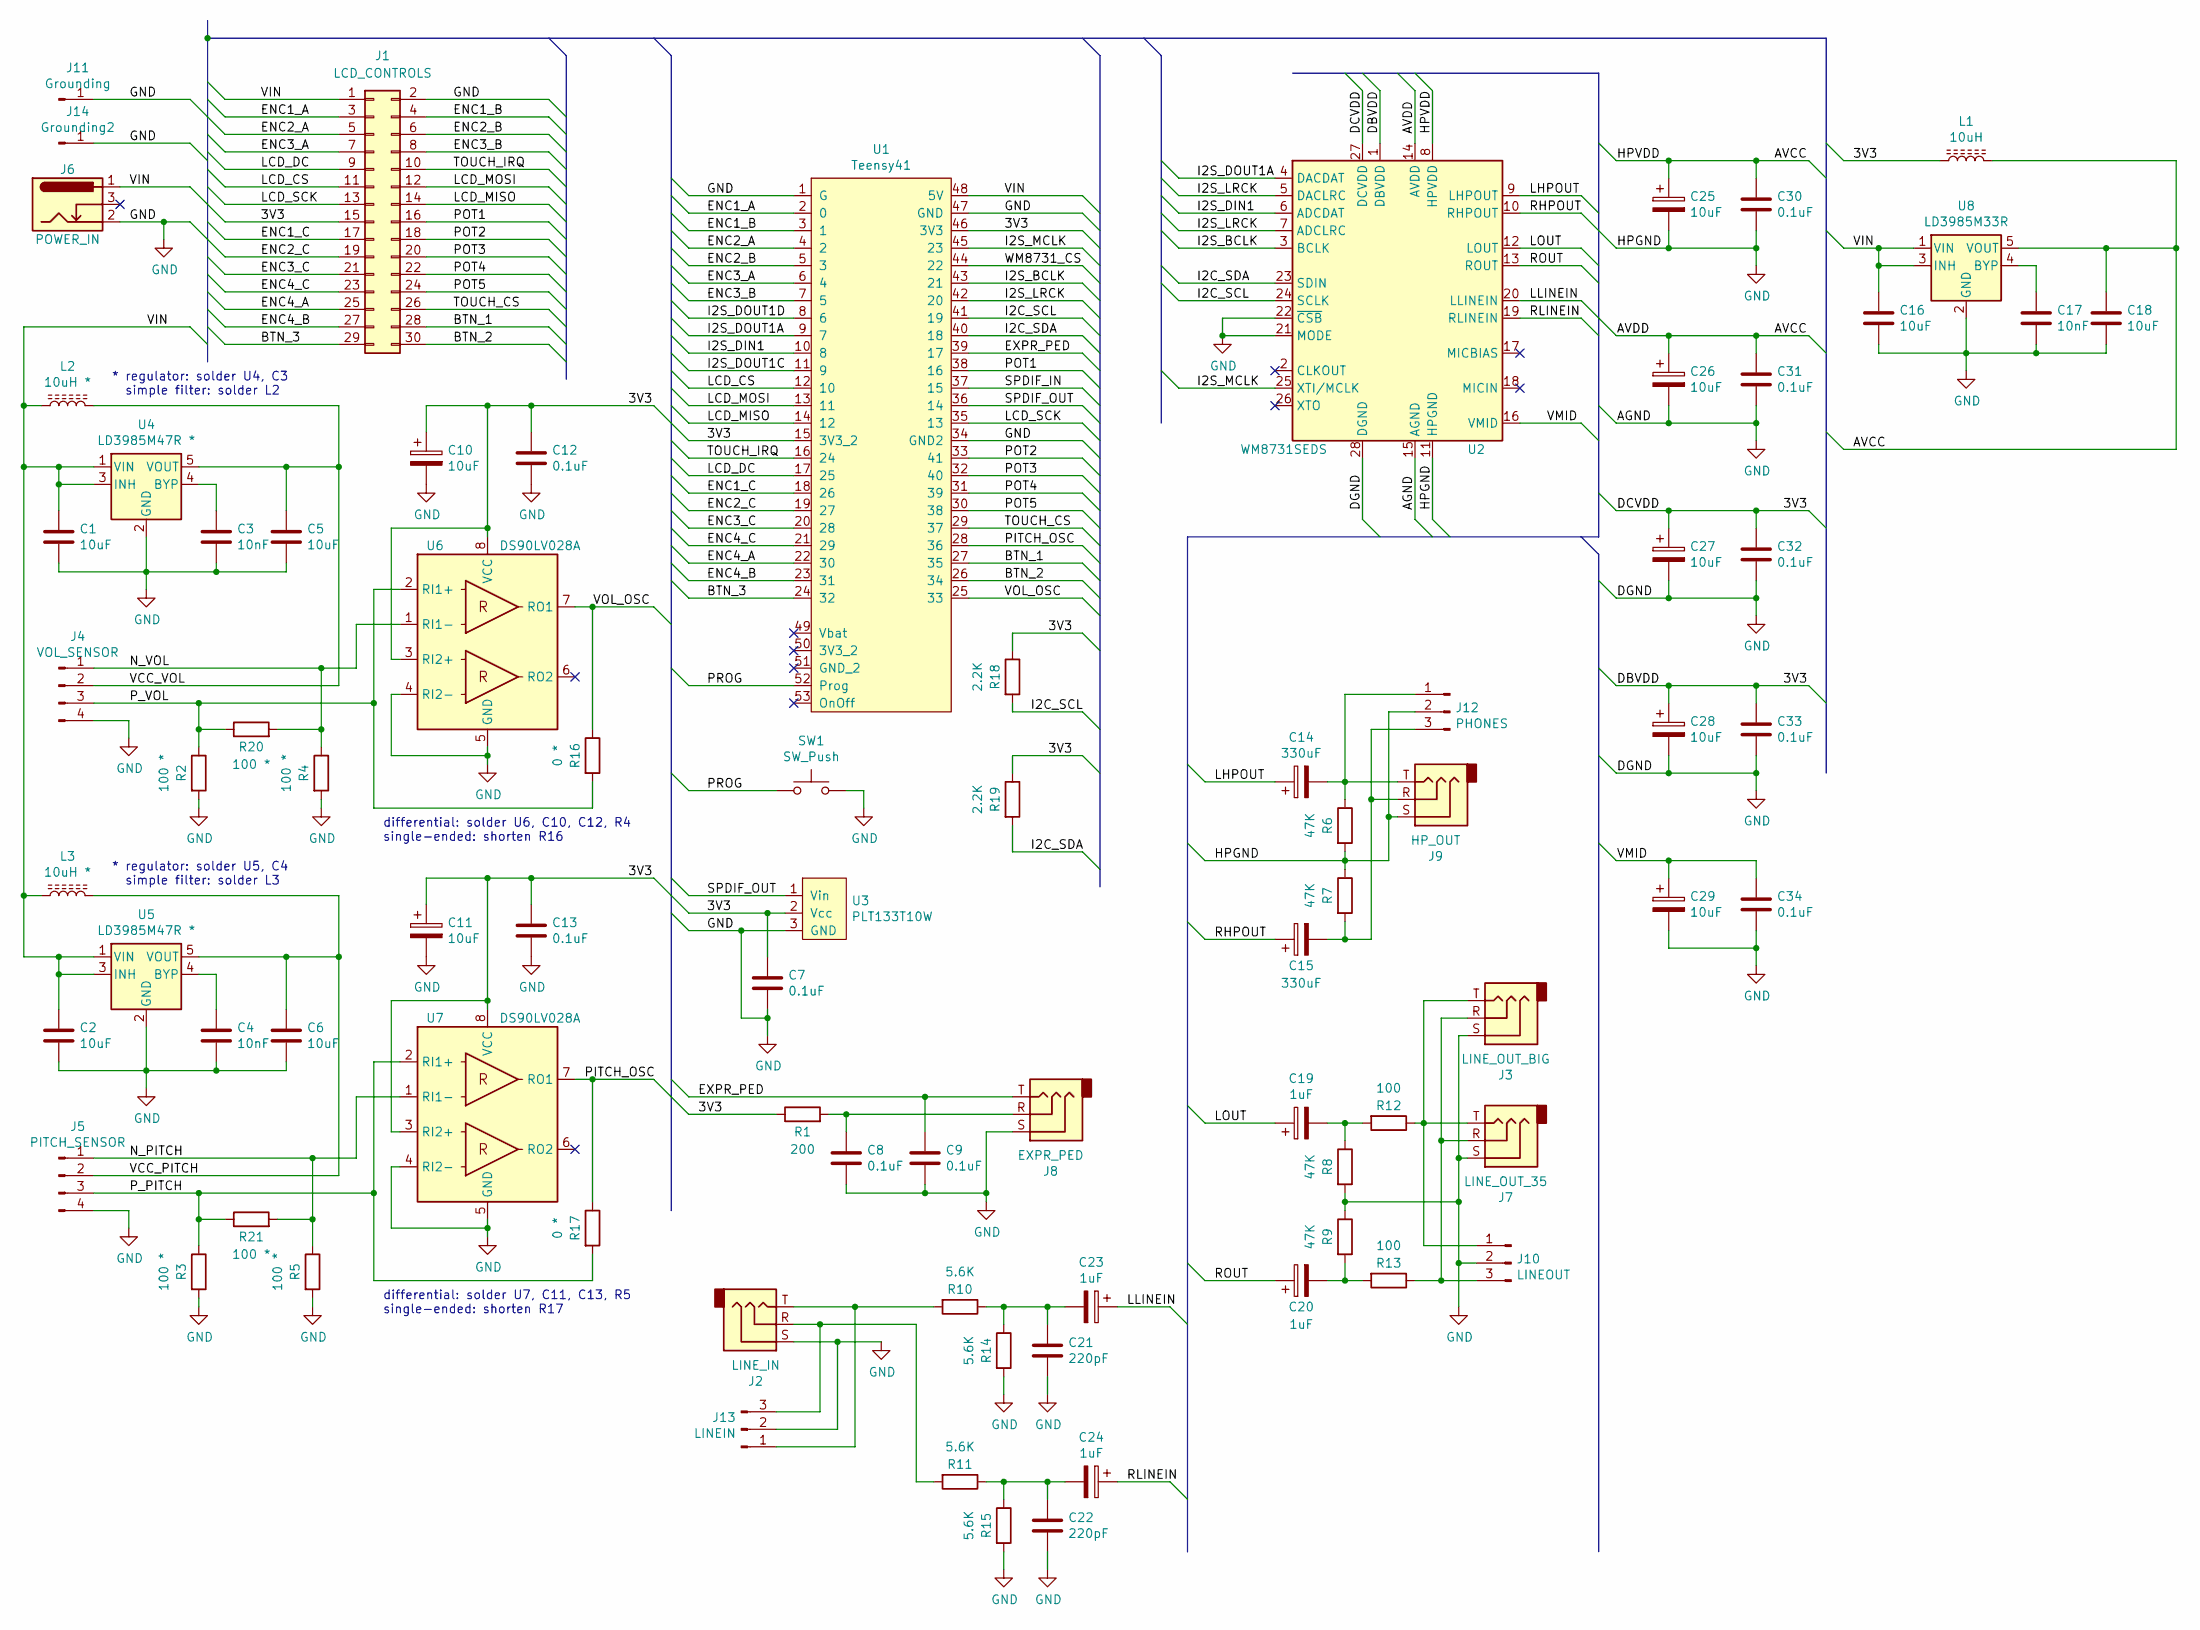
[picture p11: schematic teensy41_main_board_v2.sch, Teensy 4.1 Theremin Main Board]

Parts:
C1, C2, C5, C6, C16, C18: 10uF; C_0805_2012Metric_Pad1.18x1.45mm_HandSolder
C3, C4, C17: 10nF; C_0805_2012Metric_Pad1.18x1.45mm_HandSolder
C7, C8, C9, C12, C13, C30, C31, C32, C33, C34: 0.1uF; C_0805_2012Metric_Pad1.18x1.45mm_HandSolder
C10, C11, C25, C26, C27, C28, C29: 10uF; CP_EIA-3216-18_Kemet-A_Pad1.58x1.35mm_HandSolder
C14, C15: 330uF; CP_Radial_D6.3mm_P2.50mm
C19, C20, C23, C24: 1uF; CP_Radial_D5.0mm_P2.00mm
C21, C22: 220pF; C_0805_2012Metric_Pad1.18x1.45mm_HandSolder
J1: LCD_CONTROLS; IDC-Header_2x15_P2.54mm_Vertical
J2: LINE_IN; Jack_3.5mm_CUI_SJ1-3533NG_Horizontal
J3: LINE_OUT_BIG; Jack_6.35mm_ST_008G_04
J4: VOL_SENSOR; PinHeader_1x04_P2.54mm_Horizontal
J5: PITCH_SENSOR; PinHeader_1x04_P2.54mm_Horizontal
J6: POWER_IN; BarrelJack_Wuerth_6941xx301002
J7: LINE_OUT_35; Jack_3.5mm_CUI_SJ1-3533NG_Horizontal
J8: EXPR_PED; Jack_6.35mm_ST_008G_04
J9: HP_OUT; Jack_3.5mm_CUI_SJ1-3533NG_Horizontal
J10: LINEOUT; PinHeader_1x03_P2.54mm_Vertical
J11: Grounding; PinHeader_1x01_P2.54mm_Vertical
J12: PHONES; PinHeader_1x03_P2.54mm_Vertical
J13: LINEIN; PinHeader_1x03_P2.54mm_Vertical
J14: Grounding2; PinHeader_1x01_P2.54mm_Horizontal
L1: 10uH; L_7.3x7.3_H4.5
L2, L3: 10uH *; L_7.3x7.3_H4.5
R1: 200; R_0805_2012Metric_Pad1.20x1.40mm_HandSolder
R2, R3, R4, R5, R20, R21: 100 *; R_0805_2012Metric_Pad1.20x1.40mm_HandSolder
R6, R7, R8, R9: 47K; R_0805_2012Metric_Pad1.20x1.40mm_HandSolder
R10, R11, R14, R15: 5.6K; R_0805_2012Metric_Pad1.20x1.40mm_HandSolder
R12, R13: 100; R_0805_2012Metric_Pad1.20x1.40mm_HandSolder
R16, R17: 0 *; R_0805_2012Metric_Pad1.20x1.40mm_HandSolder
R18, R19: 2.2K; R_0805_2012Metric_Pad1.20x1.40mm_HandSolder
SW1: SW_Push; SW_Tactile_SKHH_Angled
U1: Teensy41
U2: WM8731SEDS; SSOP-28_5.3x10.2mm_P0.65mm
U3: PLT133T10W
U4, U5: LD3985M47R *; SOT-23-5
U6, U7: DS90LV028A; SOIC-8_3.9x4.9mm_P1.27mm
U8: LD3985M33R; SOT-23-5

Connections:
/3V3: C7.1, C10.1, C11.1, C12.1, C13.1, C27.1, C28.1, C32.1, C33.1, J1.15, L1.1, R1.1, R18.1, R19.1, U1.15 (3V3_2), U1.46 (3V3), U2.1 (DBVDD), U2.27 (DCVDD), U3.2 (Vcc), U6.3 (RI2+), U6.8 (VCC), U7.3 (RI2+), U7.8 (VCC)
/AVCC: C18.1, C25.1, C26.1, C30.1, C31.1, L1.2, U2.8 (HPVDD), U2.14 (AVDD), U8.5 (VOUT)
/BTN_1: J1.28, U1.27 (35)
/BTN_2: J1.30, U1.26 (34)
/BTN_3: J1.29, U1.24 (32)
/ENC1_A: J1.3, U1.2 (0)
/ENC1_B: J1.4, U1.3 (1)
/ENC1_C: J1.17, U1.18 (26)
/ENC2_A: J1.5, U1.4 (2)
/ENC2_B: J1.6, U1.5 (3)
/ENC2_C: J1.19, U1.19 (27)
/ENC3_A: J1.7, U1.6 (4)
/ENC3_B: J1.8, U1.7 (5)
/ENC3_C: J1.21, U1.20 (28)
/ENC4_A: J1.25, U1.22 (30)
/ENC4_B: J1.27, U1.23 (31)
/ENC4_C: J1.23, U1.21 (29)
/EXPR_PED: C9.1, J8.T, U1.39 (17)
/I2C_SCL: R18.2, U1.41 (19), U2.24 (SCLK)
/I2C_SDA: R19.2, U1.40 (18), U2.23 (SDIN)
/I2S_BCLK: U1.43 (21), U2.3 (BCLK)
/I2S_DIN1: U1.10 (8), U2.6 (ADCDAT)
/I2S_DOUT1A: U1.9 (7), U2.4 (DACDAT)
/I2S_DOUT1C: U1.11 (9)
/I2S_DOUT1D: U1.8 (6)
/I2S_LRCK: U1.42 (20), U2.5 (DACLRC), U2.7 (ADCLRC)
/I2S_MCLK: U1.45 (23), U2.25 (XTI/MCLK)
/LCD_CS: J1.11, U1.12 (10)
/LCD_DC: J1.9, U1.17 (25)
/LCD_MISO: J1.14, U1.14 (12)
/LCD_MOSI: J1.12, U1.13 (11)
/LCD_SCK: J1.13, U1.35 (13)
/LHPOUT: C14.1, U2.9 (LHPOUT)
/LLINEIN: C23.1, U2.20 (LLINEIN)
/LOUT: C19.1, U2.12 (LOUT)
/N_PITCH: J5.1, R5.1, R21.2, U7.1 (RI1-)
/N_VOL: J4.1, R4.1, R20.2, U6.1 (RI1-)
/PITCH_OSC: R17.1, U1.28 (36), U7.7 (RO1)
/POT1: J1.16, U1.38 (16)
/POT2: J1.18, U1.33 (41)
/POT3: J1.20, U1.32 (40)
/POT4: J1.22, U1.31 (39)
/POT5: J1.24, U1.30 (38)
/PROG: SW1.1, U1.52 (Prog)
/P_PITCH: J5.3, R3.1, R17.2, R21.1, U7.2 (RI1+)
/P_VOL: J4.3, R2.1, R16.2, R20.1, U6.2 (RI1+)
/RHPOUT: C15.1, U2.10 (RHPOUT)
/RLINEIN: C24.1, U2.19 (RLINEIN)
/ROUT: C20.1, U2.13 (ROUT)
/SPDIF_IN: U1.37 (15)
/SPDIF_OUT: U1.36 (14), U3.1 (Vin)
/TOUCH_CS: J1.26, U1.29 (37)
/TOUCH_IRQ: J1.10, U1.16 (24)
/VCC_PITCH: C6.1, J5.2, L3.2, U5.5 (VOUT)
/VCC_VOL: C5.1, J4.2, L2.2, U4.5 (VOUT)
/VIN: C1.1, C2.1, C16.1, J1.1, J6.1, L2.1, L3.1, U1.48 (5V), U4.1 (VIN), U4.3 (INH), U5.1 (VIN), U5.3 (INH), U8.1 (VIN), U8.3 (INH)
/VMID: C29.1, C34.1, U2.16 (VMID)
/VOL_OSC: R16.1, U1.25 (33), U6.7 (RO1)
/WM8731_CS: U1.44 (22)
GND: C1.2, C2.2, C3.2, C4.2, C5.2, C6.2, C7.2, C8.2, C9.2, C10.2, C11.2, C12.2, C13.2, C16.2, C17.2, C18.2, C21.2, C22.2, C25.2, C26.2, C27.2, C28.2, C29.2, C30.2, C31.2, C32.2, C33.2, C34.2, J1.2, J2.S, J3.S, J4.4, J5.4, J6.2, J7.S, J8.S, J9.S, J10.2, J11.1, J12.2, J13.2, J14.1, R2.2, R3.2, R4.2, R5.2, R6.2, R7.1, R8.2, R9.1, R14.2, R15.2, SW1.2, U1.1 (G), U1.34 (GND2), U1.47 (GND), U2.11 (HPGND), U2.15 (AGND), U2.21 (MODE), U2.22 (~CSB), U2.28 (DGND), U3.3 (GND), U4.2 (GND), U5.2 (GND), U6.4 (RI2-), U6.5 (GND), U7.4 (RI2-), U7.5 (GND), U8.2 (GND)
unnamed: C3.1, U4.4 (BYP)
unnamed: C4.1, U5.4 (BYP)
unnamed: C8.1, J8.R, R1.2
unnamed: C14.2, J9.T, J12.1, R6.1
unnamed: C15.2, J9.R, J12.3, R7.2
unnamed: C17.1, U8.4 (BYP)
unnamed: C19.2, R8.1, R12.2
unnamed: C20.2, R9.2, R13.2
unnamed: C21.1, C23.2, R10.1, R14.1
unnamed: C22.1, C24.2, R11.1, R15.1
unnamed: J3.T, J7.T, J10.1, R12.1
unnamed: J3.R, J7.R, J10.3, R13.1
unnamed: J2.T, J13.1, R10.2
unnamed: J2.R, J13.3, R11.2

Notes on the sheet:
* regulator: solder U5, C4 simple filter: solder L3
* regulator: solder U4, C3 simple filter: solder L2
differential: solder U7, C11, C13, R5 single-ended: shorten R17
differential: solder U6, C10, C12, R4 single-ended: shorten R16

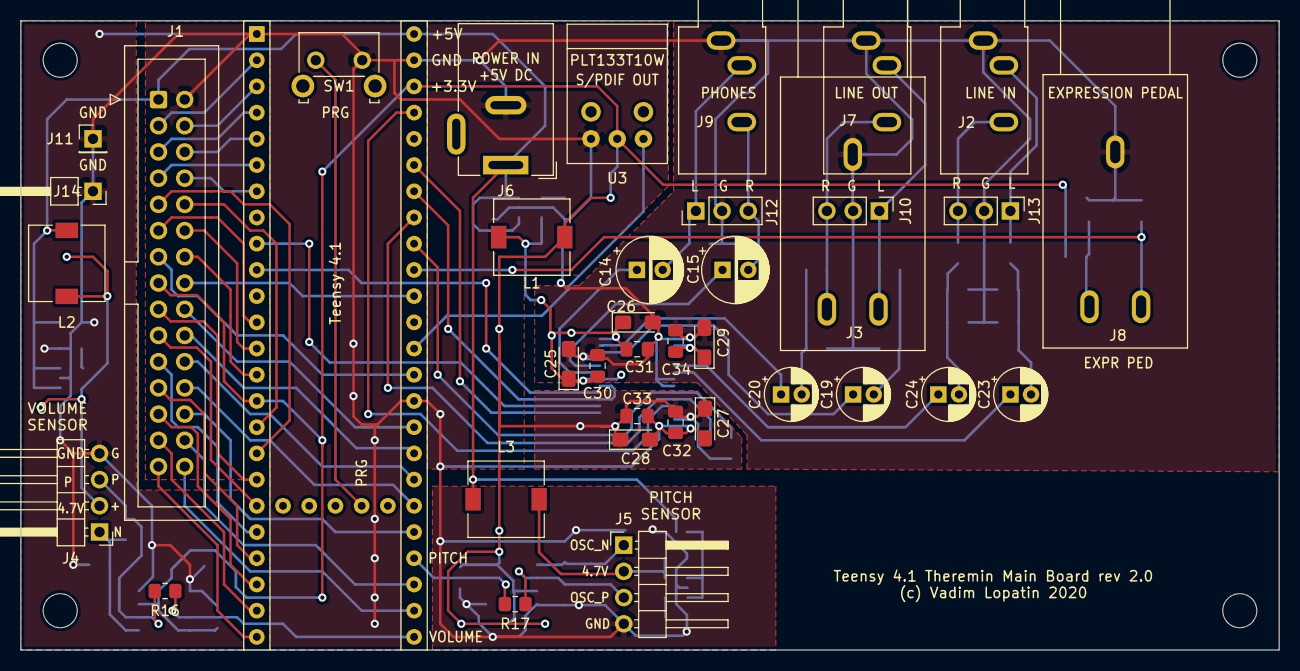
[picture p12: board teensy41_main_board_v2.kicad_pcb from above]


Board: 2 copper layers, 121.9 x 61.0 mm, 81 parts (43 on the bottom side), 70 nets.

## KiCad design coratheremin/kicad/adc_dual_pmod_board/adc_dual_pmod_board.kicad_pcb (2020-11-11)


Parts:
C1, C2, C19, C20, C21, C22: 2.2uF; C_0805_2012Metric_Pad1.18x1.45mm_HandSolder
C3, C4, C27, C28, C29, C30, C37, C38: 0.01uF; C_0805_2012Metric_Pad1.18x1.45mm_HandSolder
C5, C6, C31, C32, C33, C34: 10uF; C_0805_2012Metric_Pad1.18x1.45mm_HandSolder
C7, C8, C9, C10: 200pF; C_0805_2012Metric_Pad1.18x1.45mm_HandSolder
C11, C12: 1.5nF; C_0805_2012Metric_Pad1.18x1.45mm_HandSolder
C13, C14, C15, C16, C23, C24, C25, C26, C35, C36: 0.1uF; C_0805_2012Metric_Pad1.18x1.45mm_HandSolder
C17, C18: 1nF; C_0805_2012Metric_Pad1.18x1.45mm_HandSolder
J1: PITCH; PinHeader_1x04_P2.54mm_Horizontal
J2: VOLUME; PinHeader_1x04_P2.54mm_Horizontal
J3: PMOD_A; PinHeader_2x06_P2.54mm_Horizontal
J4: PMOD_B; PinHeader_2x06_P2.54mm_Horizontal
J5: AUX1; PinSocket_1x05_P2.54mm_Vertical
J6: Conn_mount; PinSocket_1x03_P2.54mm_Vertical
L1, L2, L3, L4: 120uH; L_1210_3225Metric_Pad1.42x2.65mm_HandSolder
L5, L6: 15uH; L_1210_3225Metric_Pad1.42x2.65mm_HandSolder
R1, R2, R3, R4, R5, R6, R7, R8: 47; R_0805_2012Metric_Pad1.20x1.40mm_HandSolder
U1, U2: LP2985-4.5; SOT-23-5
U3, U4: LP2985-3.3; SOT-23-5
U5, U6: AD9283; SSOP-20-wide-7-P0.65

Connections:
+3.3VA: C34.1, C36.1, C38.1, J4.1, J4.2, U6.15 (VDD)
+3V3: C33.1, C35.1, C37.1, J3.1, J3.2, U5.15 (VDD)
+5V: C1.1, C2.1, C19.1, C20.1, J5.1, U1.1 (VIN), U1.3 (ON/~OFF~), U2.1 (VIN), U2.3 (ON/~OFF~), U3.1 (VIN), U3.3 (ON/~OFF~), U4.1 (VIN), U4.3 (ON/~OFF~)
/A0: J3.11, U5.20 (DO0)
/A1: J3.12, U5.19 (DO1)
/A2: J3.9, U5.18 (DO2)
/A3: J3.10, U5.17 (DO3)
/A4: J3.7, U5.14 (DO4)
/A5: J3.8, U5.13 (DO5)
/A6: J3.5, U5.12 (DO6)
/A7: J3.6, U5.11 (DO7)
/AIN_N: C14.1, U5.6 (Ain-)
/AIN_P: C13.1, U5.7 (Ain+)
/A_N: C8.2, J1.1, R2.1
/A_P: C7.2, J1.3, R1.1
/A_VCC: C5.1, J1.2, U1.5 (VOUT)
/B0: J4.11, U6.20 (DO0)
/B1: J4.12, U6.19 (DO1)
/B2: J4.9, U6.18 (DO2)
/B3: J4.10, U6.17 (DO3)
/B4: J4.7, U6.14 (DO4)
/B5: J4.8, U6.13 (DO5)
/B6: J4.5, U6.12 (DO6)
/B7: J4.6, U6.11 (DO7)
/BIN_N: C16.1, U6.6 (Ain-)
/BIN_P: C15.1, U6.7 (Ain+)
/B_N: C10.2, J2.1, R4.1
/B_P: C9.2, J2.3, R3.1
/B_VCC: C6.1, J2.2, U2.5 (VOUT)
/CLK: J5.2, U5.10 (CLK), U6.10 (CLK)
/VaD_A: C17.1, C21.1, C23.1, C27.1, C31.1, U3.5 (VOUT), U5.5 (VaD), U5.8 (VaD)
/VaD_B: C18.1, C22.1, C24.1, C28.1, C32.1, U4.5 (VOUT), U6.5 (VaD), U6.8 (VaD)
GND: C1.2, C3.2, C5.2, C17.2, C19.2, C21.2, C23.2, C25.2, C27.2, C29.2, C31.2, C33.2, C35.2, C37.2, J1.4, J3.3, J3.4, R1.2, R2.2, R5.1, R6.1, U1.2 (GND), U3.2 (GND), U5.1 (PWRDWN), U5.4 (GND), U5.9 (GND), U5.16 (GND)
GND2: C2.2, C4.2, C6.2, C18.2, C20.2, C22.2, C24.2, C26.2, C28.2, C30.2, C32.2, C34.2, C36.2, C38.2, J2.4, J4.3, J4.4, R3.2, R4.2, R7.1, R8.1, U2.2 (GND), U4.2 (GND), U6.1 (PWRDWN), U6.4 (GND), U6.9 (GND), U6.16 (GND)
unnamed: C3.1, U1.4 (BP)
unnamed: C4.1, U2.4 (BP)
unnamed: C7.1, L1.1
unnamed: C8.1, L2.1
unnamed: C9.1, L3.1
unnamed: C10.1, L4.1
unnamed: C11.1, C14.2, L2.2, L5.2, R6.2
unnamed: C11.2, C13.2, L1.2, L5.1, R5.2
unnamed: C12.1, C16.2, L4.2, L6.2, R8.2
unnamed: C12.2, C15.2, L3.2, L6.1, R7.2
unnamed: C25.1, U5.2 (VREFout), U5.3 (VREFin)
unnamed: C26.1, U6.2 (VREFout), U6.3 (VREFin)
unnamed: C29.1, U3.4 (BP)
unnamed: C30.1, U4.4 (BP)



Board: 2 copper layers, 49.5 x 57.2 mm, 64 parts (58 on the bottom side), 48 nets.

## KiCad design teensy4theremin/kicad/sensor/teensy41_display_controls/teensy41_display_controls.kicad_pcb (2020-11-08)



Board: 2 copper layers, 135.9 x 78.7 mm, 71 parts (58 on the bottom side), 46 nets.

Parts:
C1, C2, C3, C4, C5, C8, C9, C25, C26: 0.1uF; C_0805_2012Metric_Pad1.18x1.45mm_HandSolder
C6, C7: 1uF; C_0805_2012Metric_Pad1.18x1.45mm_HandSolder
C10, C11, C12, C13, C14, C15, C16, C17, C18, C19, C20, C21, C22, C23, C24: 0.01uF; C_0805_2012Metric_Pad1.18x1.45mm_HandSolder
J1: MCU_CONN; IDC-Header_2x15_P2.54mm_Vertical
R1: 100; R_0805_2012Metric_Pad1.20x1.40mm_HandSolder
R2, R3, R4, R5, R6, R7, R8, R9, R10, R11, R12, R13, R14, R15, R16, R17, R18, R19, R20, R21, R22, R23, R24, R25, R26, R27, R28, R29, R30, R31: 10K; R_0805_2012Metric_Pad1.20x1.40mm_HandSolder
RV1, RV2, RV3, RV4, RV5: 25K; Potentiometer_TT_P0915N
SW1: ENC1; RotaryEncoder_Alps_EC11E-Switch_Vertical_H20mm
SW2: ENC2; RotaryEncoder_Alps_EC11E-Switch_Vertical_H20mm
SW3: ENC3; RotaryEncoder_Alps_EC11E-Switch_Vertical_H20mm
SW4: ENC4; RotaryEncoder_Alps_EC11E-Switch_Vertical_H20mm
SW5: BTN1; SW_PUSH_6mm_H9.5mm
SW6: BTN2; SW_PUSH_6mm_H9.5mm
SW7: BTN3; SW_PUSH_6mm_H9.5mm
U1: TeensyLCD; TeensyLCD_ILI9341

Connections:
+3V3: C6.1, C8.1, C25.1, C26.1, J1.15, R2.2, R3.2, R4.2, R14.2, R15.1, R16.2, R17.1, R18.2, R19.1, R23.1, R24.1, R25.1, R28.2, R29.1, R31.1, RV1.3, RV2.3, RV3.3, RV4.3, RV5.3, U1.4
+5V: C7.1, C9.1, J1.1, R1.2, U1.1
/BTN1: C10.1, J1.28, R5.1
/BTN2: C11.1, J1.30, R6.1
/BTN3: C12.1, J1.29, R7.1
/ENC1_A: C13.2, J1.3, R8.2
/ENC1_B: C14.1, J1.4, R9.1
/ENC1_C: C19.2, J1.17, R20.1
/ENC2_A: C15.2, J1.5, R10.2
/ENC2_B: C16.1, J1.6, R11.1
/ENC2_C: C20.2, J1.19, R21.1
/ENC3_A: C17.2, J1.7, R12.2
/ENC3_B: C18.1, J1.8, R13.1
/ENC3_C: C21.2, J1.21, R22.1
/ENC4_A: C22.2, J1.25, R26.2
/ENC4_B: C23.1, J1.27, R27.1
/ENC4_C: C24.2, J1.23, R30.1
/LCD_CS: J1.11, U1.3
/LCD_DC: J1.9, U1.5
/MISO: J1.14, U1.9, U1.13
/MOSI: J1.12, U1.6, U1.12
/POT1: C1.1, J1.16, RV1.2
/POT2: C2.1, J1.18, RV2.2
/POT3: C3.1, J1.20, RV3.2
/POT4: C4.1, J1.22, RV4.2
/POT5: C5.1, J1.24, RV5.2
/SCK: J1.13, U1.7, U1.10
/T_CS: J1.26, U1.11
/T_IRQ: J1.10, U1.14
GND: C1.2, C2.2, C3.2, C4.2, C5.2, C6.2, C7.2, C8.2, C9.2, C10.2, C11.2, C12.2, C13.1, C14.2, C15.1, C16.2, C17.1, C18.2, C19.1, C20.1, C21.1, C22.1, C23.2, C24.1, C25.2, C26.2, J1.2, RV1.1, RV2.1, RV3.1, RV4.1, RV5.1, SW1.C, SW1.S1, SW2.C, SW2.S1, SW3.C, SW3.S1, SW4.C, SW4.S1, SW5.1, SW6.1, SW7.1, U1.2
unnamed: R1.1, U1.8
unnamed: R2.1, R5.2, SW5.2
unnamed: R3.1, R6.2, SW6.2
unnamed: R4.1, R7.2, SW7.2
unnamed: R10.1, R16.1, SW2.A
unnamed: R11.2, R17.2, SW2.B
unnamed: R12.1, R18.1, SW3.A
unnamed: R13.2, R19.2, SW3.B
unnamed: R8.1, R14.1, SW1.A
unnamed: R9.2, R15.2, SW1.B
unnamed: R20.2, R23.2, SW1.S2
unnamed: R21.2, R24.2, SW2.S2
unnamed: R22.2, R25.2, SW3.S2
unnamed: R26.1, R28.1, SW4.A
unnamed: R27.2, R29.2, SW4.B
unnamed: R30.2, R31.2, SW4.S2

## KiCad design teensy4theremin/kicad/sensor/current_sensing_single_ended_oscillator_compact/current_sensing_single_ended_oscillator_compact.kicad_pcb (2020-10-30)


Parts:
C1: 1pF; C_0805_2012Metric_Pad1.15x1.40mm_HandSolder
C2, C3, C4, C5: 6.8pF; C_0805_2012Metric_Pad1.15x1.40mm_HandSolder
C6: 1uF; C_0805_2012Metric_Pad1.15x1.40mm_HandSolder
C7, C13: 10nF; C_0805_2012Metric_Pad1.15x1.40mm_HandSolder
C8, C12: 2.2uF; C_0805_2012Metric_Pad1.15x1.40mm_HandSolder
C9, C10: 0.1uF; C_0805_2012Metric_Pad1.15x1.40mm_HandSolder
C11: 4.7uF; CP_EIA-3528-21_Kemet-B_Pad1.50x2.35mm_HandSolder
C14: 1nF; C_0805_2012Metric_Pad1.15x1.40mm_HandSolder
J1: ANTENNA; PinHeader_1x02_P2.54mm_Horizontal
J2: INDUCTOR_OUT; PinHeader_1x01_P2.54mm_Horizontal
J3: INDUCTOR_IN; PinHeader_1x01_P2.54mm_Horizontal
J6: OSC; PinHeader_1x04_P2.54mm_Horizontal
R1: 12; R_0805_2012Metric_Pad1.20x1.40mm_HandSolder
R2, R3: 10; R_0805_2012Metric_Pad1.20x1.40mm_HandSolder
R4, R5: 100; R_0805_2012Metric_Pad1.20x1.40mm_HandSolder
TP1: Antenna Voltage Swing; PinHeader_1x01_P1.27mm_Vertical
TP2: +3.3V; PinHeader_1x01_P1.27mm_Vertical
TP3: GND; PinHeader_1x01_P1.27mm_Vertical
U1: 4220CZ6; TSOP-6_1.65x3.05mm_P0.95mm
U2: LP2985AIM5-3.3; SOT-23-5
U3: LT1711CMS8; MSOP-8_3x3mm_P0.65mm

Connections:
/3V3_A: C8.1, C9.1, C10.1, C11.1, C12.1, C13.1, C14.1, TP2.1, U1.5 (VCC), U2.5 (VOUT), U3.1 (V+)
/5V: C6.1, J6.3, U2.1 (VIN), U2.3 (INH)
/DRIVE: R1.1, R3.1, U3.3 (-), U3.8 (~Q)
/IND_IN: J3.1, R1.2, U1.6 (ESD4), U3.2 (+)
/OUTN: J6.4, R3.2, R4.1
/OUTP: J6.2, R2.2, R5.2
GND: C5.2, C6.2, C7.2, C8.2, C9.2, C10.2, C11.2, C12.2, C13.2, C14.2, J6.1, R4.2, R5.1, TP3.1, U1.2 (GND), U2.2 (GND), U3.4 (V-), U3.5 (LATCH), U3.6 (GND)
unnamed: C1.1, TP1.1
unnamed: C1.2, C2.1, J1.1, J1.2, J2.1
unnamed: C2.2, C3.1
unnamed: C3.2, C4.1
unnamed: C4.2, C5.1
unnamed: C7.1, U2.4 (BYP)
unnamed: R2.1, U3.7 (Q)

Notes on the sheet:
To theremin antenna
Theremin oscillator rev 1.3 digital output square 3.3V 700..2000KHz differential or single ended Power input: +3.6 .. 6V, 50mA
L: Air core coil, 1.5-3 mH 0.1mm/0.125mm copper wire, 32mm frame diameter, 40..70mm winding length
IP4220CZ6 ESD protection is mandatory!
LDO 3.3V
To MCU or FPGA
Optional caps to reduce oscillator frequency. Decreases sensitivity. Recommended for using with Volume antenna only.
Test point for checking of antenna voltage swing. Decoupled by 1pF cap.
Current sensing resistor. Recommended values: 10..47 Ohm. Smaller value gives bigger antenna voltage swing.
Use R2, R3, R4, R5 to match line impedance and decrease ringing. R3, R4 are not needed for single ended out

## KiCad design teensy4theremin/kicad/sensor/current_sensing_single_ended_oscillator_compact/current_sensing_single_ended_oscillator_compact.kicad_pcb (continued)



Board: 2 copper layers, 70.5 x 21.1 mm, 29 parts (6 on the bottom side), 14 nets.

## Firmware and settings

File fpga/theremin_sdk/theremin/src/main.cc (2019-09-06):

/*
 * Empty C++ Application
 */

#include "theremin_ip.h"



#include "xil_types.h"
#include "xstatus.h"
#include <xscugic.h>
#include <sleep.h>
#include <xil_io.h>
#include <xil_misc_psreset_api.h>
#include "xil_cache.h"
#include "xil_cache_l.h"

#include "xpseudo_asm.h"
#include "xil_mmu.h"
#include "lcd_screen.h"
#include "bitmap_fonts.h"

//uint16_t framebuffer[SCREEN_DX*SCREEN_DY + 64]  __attribute__ ((aligned(32)));

void setLeds(int phase) {
	switch(phase & 7) {
	default:
	case 0:
		thereminIO_setLed0Color(0x8000ff);
		break;
	case 1:
		thereminIO_setLed0Color(0x404080);
		break;
	case 2:
		thereminIO_setLed0Color(0x408080);
		break;
	case 3:
		thereminIO_setLed0Color(0xff8080);
		break;
	case 4:
		thereminIO_setLed0Color(0xff8080);
		break;
	case 5:
		thereminIO_setLed0Color(0xcf4040);
		break;
	case 6:
		thereminIO_setLed0Color(0x8f2020);
		break;
	case 7:
		thereminIO_setLed0Color(0x4f1010);
		break;
	}
}

void setLCDColor(uint32_t value) {
	thereminIO_writeReg(THEREMIN_WR_REG_LCD_CONTROL, 0x80000000|value);
}

// AMP3 PMOD JP6 loaded
#define AMP3_I2C_ADDRESS 0x34
// AMP3 PMOD JP6 unloaded
//#define AMP3_I2C_ADDRESS 0x36
#define I2C_STATUS_BIT_READY 0x100
#define I2C_STATUS_BIT_ERROR 0x200

void thereminAudio_i2cWrite(uint8_t addr, uint8_t data) {
	//
}

uint32_t thereminAudio_i2cRead(uint8_t reg) {

	uint32_t status = thereminIO_readReg(THEREMIN_RD_REG_AUDIO_I2C);
	while ( !(status & I2C_STATUS_BIT_READY) ) {
		xil_printf("i2c status is %3x - waiting for ready state\r\n", status);
		usleep(500000);
		status = thereminIO_readReg(THEREMIN_RD_REG_AUDIO_I2C);
	}
	uint32_t command = 0x000000; // read
	command |= AMP3_I2C_ADDRESS << 16;
	command |= ((uint32_t)reg) << 8;
	thereminIO_writeReg(THEREMIN_WR_REG_AUDIO_I2C, command);
	status = thereminIO_readReg(THEREMIN_RD_REG_AUDIO_I2C);
	while ( !(status & I2C_STATUS_BIT_READY) ) {
		status = thereminIO_readReg(THEREMIN_RD_REG_AUDIO_I2C);
	}
	xil_printf("i2c status is %3x\r\n", status);
	return status & 0xff;
}

#define THEREMIN_RD_REG_ENCODERS_RAW (11*4)

uint32_t readEncodersManual() {
	uint32_t res = 0;
	for (int i = 0; i < 16; i++) {
		thereminIO_writeReg(THEREMIN_RD_REG_ENCODERS_RAW, i);
		usleep(150000);
		res = (res << 1) | (thereminIO_readReg(THEREMIN_RD_REG_ENCODERS_RAW) & 1);
	}
	return res;
}

int main()
{
	print("FPGA Theremin Project\r\n");
	sleep(1);
	print("FPGA Theremin Project\r\n");
	print("(c) Vadim Lopatin, 2019\r\n");
	print("Resetting PL\r\n");
	thereminIO_init();
	//setLeds(0);
	print("    Done\r\n");
	usleep(1000);

	lcd_init();
    lcd_fill_rect(0, 0, SCREEN_DX, SCREEN_DY, 0x0111);
    lcd_fill_rect(6, 5, 120, 50, 0x0f84);
    lcd_fill_rect(5, 55, 121, 100, 0x058e);

    lcd_fill_rect(400, 100, 700, 150, 0x0000);
    lcd_fill_rect(400, 200, 700, 250, 0x0f00);
    lcd_fill_rect(400, 300, 700, 350, 0x00f0);
    lcd_fill_rect(400, 400, 700, 450, 0x000f);

    for (int x = 50; x < SCREEN_DX; x+=5) {
        lcd_draw_line(5, 5, x, SCREEN_DY-1, 0x305020);
    }

    lcd_draw_text(XSMALL_FONT, 10, 100, 0x0ff, "Hello world! XSMALL 0123456789", -32768);
    lcd_draw_text(SMALL_FONT,  10, 150, 0x0ff, "Hello world! SMALL 0123456789", -32768);
    lcd_draw_text(MEDIUM_FONT, 10, 200, 0x0ff, "Hello world! MEDIUM  0123456789", -32768);
    lcd_draw_text(LARGE_FONT,  10, 250, 0x0ff, "Hello world! LARGE", -32768);
    lcd_draw_text(XLARGE_FONT, 10, 300, 0x0ff, "Hello world! XLARGE", -32768);

    lcd_draw_text(LARGE_FONT, 600, 50, 0xfff, "LARGE WHITE", -32768);
    lcd_draw_text(XLARGE_FONT, 600, 150, 0xfff, "XLARGE WHITE", -32768);

    lcd_draw_text(MEDIUM_FONT, 460, 110, 0x000, "MEDIUM black", -32768);

    lcd_draw_text(LARGE_FONT, 100, 80, 0xfff, "Cora Z7 FPGA Theremin Project", -32768);

    lcd_draw_rect(400, 50, 500, 100, 5, CL_RED, CL_YELLOW);
    lcd_draw_rect(450, 70, 550, 120, 7, CL_BLUE, CL_TRANSPARENT);

    lcd_flush();
	//thereminIO_flushCache(framebuffer, SCREEN_DX*SCREEN_DX*2);
	//xil_printf("Setting framebuffer address to %08x\r\n", framebuffer);
	//thereminLCD_setFramebufferAddress(framebuffer);
	thereminIO_setBacklightBrightness(0x40);
	print("    Done\r\n");
	usleep(10000);

	for (int i = 0; i < 16; i++) {
		xil_printf("REG[%d] = %08x\r\n", i, thereminIO_readReg(i*4));
	}

	xil_printf("i2c reg 0 = %2x \r\n", thereminAudio_i2cRead(0));
	xil_printf("i2c reg 2 = %2x \r\n", thereminAudio_i2cRead(2));

	//thereminIO_setLed0Color(0x8000ff);
	//thereminIO_setLed1Color(0x000020);
	uint32_t prevEnc0 = thereminIO_readReg(THEREMIN_RD_REG_ENCODER_0);
	uint32_t prevEnc1 = thereminIO_readReg(THEREMIN_RD_REG_ENCODER_1);
	uint32_t prevEnc2 = thereminIO_readReg(THEREMIN_RD_REG_ENCODER_2);
	uint32_t prevEncRaw = 0; //thereminIO_readReg(10) & 0xffff;


	thereminIO_writeReg(0*4, 0x00000007);

	int phase = 0;
	uint32_t counter = 0;
	for (;;counter++) {
		//print("readreg: ");
		uint32_t rowIndex = thereminLCD_getCurrentRowIndex();
//		xil_printf("Row index=%6d   irqs=%d\r\n",
//				rowIndex, 0 //irq_counter
//				);
//		print("..");
		usleep(10000);

		int ax = counter * 3 % 751;
		uint16_t acolor = ((counter / 3) & 0xf) | ((counter * 5)&0x0f0) | ((counter * 31)&0xf00);
		lcd_fill_rect(ax, 400, ax + 50, 450, acolor);
		lcd_flush();

//		print(".\r\n");
		phase = (phase + 1)&7;
		//setLeds(phase);
		if (phase & 1) {
			//setLCDColor(0xfc8);
			//thereminIO_setBacklightBrightness(0x80);
		} else {
			//setLCDColor(0x46a);
			//thereminIO_setBacklightBrightness(0x20);
		}
//		uint32_t newEnc0 = thereminIO_readReg(THEREMIN_RD_REG_ENCODER_0);
//		uint32_t newEnc1 = thereminIO_readReg(THEREMIN_RD_REG_ENCODER_1);
//		uint32_t newEnc2 = thereminIO_readReg(THEREMIN_RD_REG_ENCODER_2);
//		uint32_t newEncRaw = 0; //thereminIO_readReg(10) & 0xffff;
//		if (prevEnc0 != newEnc0 || prevEnc1 != newEnc1 || prevEnc2 != newEnc2 || prevEncRaw != newEncRaw) {
//			xil_printf("Encoders:    %08x   %08x    %08x     raw:%04x\r\n",
//					newEnc0, newEnc1, newEnc2, newEncRaw
//					);
//			prevEnc0 = newEnc0;
//			prevEnc1 = newEnc1;
//			prevEnc2 = newEnc2;
//			prevEncRaw = newEncRaw;
//		}
		//uint32_t enc = readEncodersManual();
		//xil_printf("Encoders \t%4x\r\n", enc);
		uint32_t s = thereminIO_readReg(0);
		uint32_t p = thereminIO_readReg(10*4);
		int x = (s>>16)&0x3ff;
		int y = (s)&0x3ff;
		int vsync = (s>>15)&1;
		int hsync = (s>>14)&1;
		int de = (s>>13)&1;
		int expectedDE = ((x < 800) && (y < 480)) ? 0 : 1;
		int expectedVSYNC = (y >= 480+2 && y < 480+2+2) ? 0 : 1;
		int expectedHSYNC = (x >= 800+2 && x < 800+2+10) ? 0 : 1;
		//if (de != expectedDE || vsync != expectedVSYNC || hsync != expectedHSYNC)
		if (1)
			xil_printf("LCD controls: VSYNC=%d (%d)\t HSYNC=%d (%d)\t DE=%d (%d)\t x=%d\t y=%d  \t px=%04x   \tmodes=%x\r\n",
				vsync, expectedVSYNC,
				hsync, expectedHSYNC,
				de, expectedDE,
				//(s>>11)&1, (s>>10)&1,
				x,
				y,
				p&0xffff,
				(p>>16)&0xf
				);
	}
	return 0;
}

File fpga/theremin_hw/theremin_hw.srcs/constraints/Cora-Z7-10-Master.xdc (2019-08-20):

## This file is a general .xdc for the Cora Z7-10 Rev. B
## To use it in a project:
## - uncomment the lines corresponding to used pins
## - rename the used ports (in each line, after get_ports) according to the top level signal names in the project

## PL System Clock
set_property -dict { PACKAGE_PIN H16   IOSTANDARD LVCMOS33 } [get_ports { sys_clock }]; #IO_L13P_T2_MRCC_35 Sch=sysclk
create_clock -add -name sys_clk_pin -period 8.00 -waveform {0 4} [get_ports { sys_clock }];#set

## RGB LEDs
#set_property -dict { PACKAGE_PIN L15   IOSTANDARD LVCMOS33 } [get_ports { led0_b }]; #IO_L22N_T3_AD7N_35 Sch=led0_b
#set_property -dict { PACKAGE_PIN G17   IOSTANDARD LVCMOS33 } [get_ports { led0_g }]; #IO_L16P_T2_35 Sch=led0_g
#set_property -dict { PACKAGE_PIN N15   IOSTANDARD LVCMOS33 } [get_ports { led0_r }]; #IO_L21P_T3_DQS_AD14P_35 Sch=led0_r
#set_property -dict { PACKAGE_PIN G14   IOSTANDARD LVCMOS33 } [get_ports { led1_b }]; #IO_0_35 Sch=led1_b
#set_property -dict { PACKAGE_PIN L14   IOSTANDARD LVCMOS33 } [get_ports { led1_g }]; #IO_L22P_T3_AD7P_35 Sch=led1_g
#set_property -dict { PACKAGE_PIN M15   IOSTANDARD LVCMOS33 } [get_ports { led1_r }]; #IO_L23N_T3_35 Sch=led1_r

set_property -dict { PACKAGE_PIN L15   IOSTANDARD LVCMOS33 } [get_ports { RGBLED0_0_b }]; #IO_L22N_T3_AD7N_35 Sch=led0_b
set_property -dict { PACKAGE_PIN G17   IOSTANDARD LVCMOS33 } [get_ports { RGBLED0_0_g }]; #IO_L16P_T2_35 Sch=led0_g
set_property -dict { PACKAGE_PIN N15   IOSTANDARD LVCMOS33 } [get_ports { RGBLED0_0_r }]; #IO_L21P_T3_DQS_AD14P_35 Sch=led0_r
set_property -dict { PACKAGE_PIN G14   IOSTANDARD LVCMOS33 } [get_ports { RGBLED1_0_b }]; #IO_0_35 Sch=led1_b
set_property -dict { PACKAGE_PIN L14   IOSTANDARD LVCMOS33 } [get_ports { RGBLED1_0_g }]; #IO_L22P_T3_AD7P_35 Sch=led1_g
set_property -dict { PACKAGE_PIN M15   IOSTANDARD LVCMOS33 } [get_ports { RGBLED1_0_r }]; #IO_L23N_T3_35 Sch=led1_r

## Buttons
#set_property -dict { PACKAGE_PIN D20   IOSTANDARD LVCMOS33 } [get_ports { btn[0] }]; #IO_L4N_T0_35 Sch=btn[0]
#set_property -dict { PACKAGE_PIN D19   IOSTANDARD LVCMOS33 } [get_ports { btn[1] }]; #IO_L4P_T0_35 Sch=btn[1]

## Pmod Header JA
#set_property -dict { PACKAGE_PIN Y18   IOSTANDARD LVCMOS33 } [get_ports { ja[0] }]; #IO_L17P_T2_34 Sch=ja_p[1]
#set_property -dict { PACKAGE_PIN Y19   IOSTANDARD LVCMOS33 } [get_ports { ja[1] }]; #IO_L17N_T2_34 Sch=ja_n[1]
#set_property -dict { PACKAGE_PIN Y16   IOSTANDARD LVCMOS33 } [get_ports { ja[2] }]; #IO_L7P_T1_34 Sch=ja_p[2]
#set_property -dict { PACKAGE_PIN Y17   IOSTANDARD LVCMOS33 } [get_ports { ja[3] }]; #IO_L7N_T1_34 Sch=ja_n[2]
#set_property -dict { PACKAGE_PIN U18   IOSTANDARD LVCMOS33 } [get_ports { ja[4] }]; #IO_L12P_T1_MRCC_34 Sch=ja_p[3]
#set_property -dict { PACKAGE_PIN U19   IOSTANDARD LVCMOS33 } [get_ports { ja[5] }]; #IO_L12N_T1_MRCC_34 Sch=ja_n[3]
#set_property -dict { PACKAGE_PIN W18   IOSTANDARD LVCMOS33 } [get_ports { ja[6] }]; #IO_L22P_T3_34 Sch=ja_p[4]
#set_property -dict { PACKAGE_PIN W19   IOSTANDARD LVCMOS33 } [get_ports { ja[7] }]; #IO_L22N_T3_34 Sch=ja_n[4]

## Pmod Header JB
#set_property -dict { PACKAGE_PIN W14   IOSTANDARD LVCMOS33 } [get_ports { jb[0] }]; #IO_L8P_T1_34 Sch=jb_p[1]
#set_property -dict { PACKAGE_PIN Y14   IOSTANDARD LVCMOS33 } [get_ports { jb[1] }]; #IO_L8N_T1_34 Sch=jb_n[1]
#set_property -dict { PACKAGE_PIN T11   IOSTANDARD LVCMOS33 } [get_ports { jb[2] }]; #IO_L1P_T0_34 Sch=jb_p[2]
#set_property -dict { PACKAGE_PIN T10   IOSTANDARD LVCMOS33 } [get_ports { jb[3] }]; #IO_L1N_T0_34 Sch=jb_n[2]
#set_property -dict { PACKAGE_PIN V16   IOSTANDARD LVCMOS33 } [get_ports { jb[4] }]; #IO_L18P_T2_34 Sch=jb_p[3]
#set_property -dict { PACKAGE_PIN W16   IOSTANDARD LVCMOS33 } [get_ports { jb[5] }]; #IO_L18N_T2_34 Sch=jb_n[3]
#set_property -dict { PACKAGE_PIN V12   IOSTANDARD LVCMOS33 } [get_ports { jb[6] }]; #IO_L4P_T0_34 Sch=jb_p[4]
#set_property -dict { PACKAGE_PIN W13   IOSTANDARD LVCMOS33 } [get_ports { jb[7] }]; #IO_L4N_T0_34 Sch=jb_n[4]

## Crypto SDA 
#set_property -dict { PACKAGE_PIN J15   IOSTANDARD LVCMOS33 } [get_ports { crypto_sda }];

## Dedicated Analog Inputs
#set_property -dict { PACKAGE_PIN K9    IOSTANDARD LVCMOS33 } [get_ports { v_p }]; #VP_0 Sch=xadc_v_p
#set_property -dict { PACKAGE_PIN L10   IOSTANDARD LVCMOS33 } [get_ports { v_n }]; #VN_0 Sch=xadc_v_n
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

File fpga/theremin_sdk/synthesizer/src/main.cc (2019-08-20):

/*
 * Empty C++ Application
 */

#include "theremin_ip.h"

#include "xil_types.h"
#include "xstatus.h"
#include <xscugic.h>
#include <sleep.h>
#include <xil_io.h>
#include <xil_misc_psreset_api.h>
#include "xil_cache.h"
#include "xil_cache_l.h"

#include "xpseudo_asm.h"
#include "xil_mmu.h"





static volatile int32_t delay_counter = 0;
void delay(int n) {
	for (int i = 0; i < n; i++)
		delay_counter++;
}

void setLeds(int phase) {
	switch(phase & 7) {
	default:
	case 0:
		//thereminIO_setLed0Color(0x8000ff);
		thereminIO_setLed1Color(0x000020);
		break;
	case 1:
		//thereminIO_setLed0Color(0x404080);
		thereminIO_setLed1Color(0x003020);
		break;
	case 2:
		//thereminIO_setLed0Color(0x408080);
		thereminIO_setLed1Color(0x403020);
		break;
	case 3:
		//thereminIO_setLed0Color(0xff8080);
		thereminIO_setLed1Color(0x4030ff);
		break;
	case 4:
		//thereminIO_setLed0Color(0xff8080);
		thereminIO_setLed1Color(0x4030ff);
		break;
	case 5:
		//thereminIO_setLed0Color(0xcf4040);
		thereminIO_setLed1Color(0x201080);
		break;
	case 6:
		//thereminIO_setLed0Color(0x8f2020);
		thereminIO_setLed1Color(0x100040);
		break;
	case 7:
		//thereminIO_setLed0Color(0x4f1010);
		thereminIO_setLed1Color(0x000020);
		break;
	}
}


uint32_t irq_counter = 0;
void my_audio_irq() {
	irq_counter++;
	int subphase = irq_counter % (48 * 200);
	int phase = irq_counter / 48 / 200;
	if (subphase == 0)
		setLeds(phase & 7);
}

int main()
{
	thereminIO_init();
	//print("Setting audio irq handler\r\n");
	thereminAudio_setIrqHandler(&my_audio_irq);
	//print("Enabling audio IRQ\r\n");

	thereminAudio_enableIrq();
	delay(1000000);
	for(;;) {
		delay(2000000);
	}
	return 0;
}

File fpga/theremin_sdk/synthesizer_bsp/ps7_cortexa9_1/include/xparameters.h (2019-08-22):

#ifndef XPARAMETERS_H   /* prevent circular inclusions */
#define XPARAMETERS_H   /* by using protection macros */

/* Definition for CPU ID */
#define XPAR_CPU_ID 1U

/* Definitions for peripheral PS7_CORTEXA9_1 */
#define XPAR_PS7_CORTEXA9_1_CPU_CLK_FREQ_HZ 650000000


/******************************************************************/

/* Canonical definitions for peripheral PS7_CORTEXA9_1 */
#define XPAR_CPU_CORTEXA9_0_CPU_CLK_FREQ_HZ 650000000


/******************************************************************/

#include "xparameters_ps.h"

#define STDIN_BASEADDRESS 0xE0000000
#define STDOUT_BASEADDRESS 0xE0000000

/******************************************************************/

/* Platform specific definitions */
#define PLATFORM_ZYNQ
 
/* Definitions for sleep timer configuration */
#define XSLEEP_TIMER_IS_DEFAULT_TIMER
 
 
/******************************************************************/

/* Definitions for peripheral PS7_DDR_0 */
#define XPAR_PS7_DDR_0_S_AXI_BASEADDR 0x00100000
#define XPAR_PS7_DDR_0_S_AXI_HIGHADDR 0x1FFFFFFF


/******************************************************************/

/* Definitions for driver DEVCFG */
#define XPAR_XDCFG_NUM_INSTANCES 1U

/* Definitions for peripheral PS7_DEV_CFG_0 */
#define XPAR_PS7_DEV_CFG_0_DEVICE_ID 0U
#define XPAR_PS7_DEV_CFG_0_BASEADDR 0xF8007000U
#define XPAR_PS7_DEV_CFG_0_HIGHADDR 0xF80070FFU


/******************************************************************/

/* Canonical definitions for peripheral PS7_DEV_CFG_0 */
#define XPAR_XDCFG_0_DEVICE_ID XPAR_PS7_DEV_CFG_0_DEVICE_ID
#define XPAR_XDCFG_0_BASEADDR 0xF8007000U
#define XPAR_XDCFG_0_HIGHADDR 0xF80070FFU


/******************************************************************/

/* Definitions for driver DMAPS */
#define XPAR_XDMAPS_NUM_INSTANCES 2

/* Definitions for peripheral PS7_DMA_NS */
#define XPAR_PS7_DMA_NS_DEVICE_ID 0
#define XPAR_PS7_DMA_NS_BASEADDR 0xF8004000
#define XPAR_PS7_DMA_NS_HIGHADDR 0xF8004FFF


/* Definitions for peripheral PS7_DMA_S */
#define XPAR_PS7_DMA_S_DEVICE_ID 1
#define XPAR_PS7_DMA_S_BASEADDR 0xF8003000
#define XPAR_PS7_DMA_S_HIGHADDR 0xF8003FFF


/******************************************************************/

/* Canonical definitions for peripheral PS7_DMA_NS */
#define XPAR_XDMAPS_0_DEVICE_ID XPAR_PS7_DMA_NS_DEVICE_ID
#define XPAR_XDMAPS_0_BASEADDR 0xF8004000
#define XPAR_XDMAPS_0_HIGHADDR 0xF8004FFF

/* Canonical definitions for peripheral PS7_DMA_S */
#define XPAR_XDMAPS_1_DEVICE_ID XPAR_PS7_DMA_S_DEVICE_ID
#define XPAR_XDMAPS_1_BASEADDR 0xF8003000
#define XPAR_XDMAPS_1_HIGHADDR 0xF8003FFF


/******************************************************************/

/* Definitions for driver EMACPS */
#define XPAR_XEMACPS_NUM_INSTANCES 1

/* Definitions for peripheral PS7_ETHERNET_0 */
#define XPAR_PS7_ETHERNET_0_DEVICE_ID 0
#define XPAR_PS7_ETHERNET_0_BASEADDR 0xE000B000
#define XPAR_PS7_ETHERNET_0_HIGHADDR 0xE000BFFF
#define XPAR_PS7_ETHERNET_0_ENET_CLK_FREQ_HZ 125000000
#define XPAR_PS7_ETHERNET_0_ENET_SLCR_1000MBPS_DIV0 8
#define XPAR_PS7_ETHERNET_0_ENET_SLCR_1000MBPS_DIV1 1
#define XPAR_PS7_ETHERNET_0_ENET_SLCR_100MBPS_DIV0 8
#define XPAR_PS7_ETHERNET_0_ENET_SLCR_100MBPS_DIV1 5
#define XPAR_PS7_ETHERNET_0_ENET_SLCR_10MBPS_DIV0 8
#define XPAR_PS7_ETHERNET_0_ENET_SLCR_10MBPS_DIV1 50
#define XPAR_PS7_ETHERNET_0_ENET_TSU_CLK_FREQ_HZ 0


/******************************************************************/

#define XPAR_PS7_ETHERNET_0_IS_CACHE_COHERENT 0
#define XPAR_XEMACPS_0_IS_CACHE_COHERENT 0
/* Canonical definitions for peripheral PS7_ETHERNET_0 */
#define XPAR_XEMACPS_0_DEVICE_ID XPAR_PS7_ETHERNET_0_DEVICE_ID
#define XPAR_XEMACPS_0_BASEADDR 0xE000B000
#define XPAR_XEMACPS_0_HIGHADDR 0xE000BFFF
#define XPAR_XEMACPS_0_ENET_CLK_FREQ_HZ 125000000
#define XPAR_XEMACPS_0_ENET_SLCR_1000Mbps_DIV0 8
#define XPAR_XEMACPS_0_ENET_SLCR_1000Mbps_DIV1 1
#define XPAR_XEMACPS_0_ENET_SLCR_100Mbps_DIV0 8
#define XPAR_XEMACPS_0_ENET_SLCR_100Mbps_DIV1 5
#define XPAR_XEMACPS_0_ENET_SLCR_10Mbps_DIV0 8
#define XPAR_XEMACPS_0_ENET_SLCR_10Mbps_DIV1 50
#define XPAR_XEMACPS_0_ENET_TSU_CLK_FREQ_HZ 0


/******************************************************************/


/* Definitions for peripheral PS7_AFI_0 */
#define XPAR_PS7_AFI_0_S_AXI_BASEADDR 0xF8008000
#define XPAR_PS7_AFI_0_S_AXI_HIGHADDR 0xF8008FFF


/* Definitions for peripheral PS7_AFI_1 */
#define XPAR_PS7_AFI_1_S_AXI_BASEADDR 0xF8009000
#define XPAR_PS7_AFI_1_S_AXI_HIGHADDR 0xF8009FFF


/* Definitions for peripheral PS7_AFI_2 */
#define XPAR_PS7_AFI_2_S_AXI_BASEADDR 0xF800A000
#define XPAR_PS7_AFI_2_S_AXI_HIGHADDR 0xF800AFFF


/* Definitions for peripheral PS7_AFI_3 */
#define XPAR_PS7_AFI_3_S_AXI_BASEADDR 0xF800B000
#define XPAR_PS7_AFI_3_S_AXI_HIGHADDR 0xF800BFFF


/* Definitions for peripheral PS7_DDRC_0 */
#define XPAR_PS7_DDRC_0_S_AXI_BASEADDR 0xF8006000
#define XPAR_PS7_DDRC_0_S_AXI_HIGHADDR 0xF8006FFF
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

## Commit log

2018-09-27 share cabinet laser cut design and oscillator design
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2019-08-16 fix LED pwm
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2019-09-02 encoders and buttons rework
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2019-09-04 fixes for xil sdk
    [main.cc]
2019-10-10 sensor schematic update
    [_saved_phase_shift_sensor.sch, phase_shift_sensor.kicad_pcb, phase_shift_sensor.sch]
2019-10-10 ltspice model v3
    [teensy4_pins_layout.xlsx]
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2019-11-08 opamp oscillator kicad
    [opamp_sine_oscillator.kicad_pcb, opamp_sine_oscillator.sch]
2019-11-12 sine oscillator proto PCB
    [opamp_sine_oscillator_proto.kicad_pcb, opamp_sine_oscillator_proto.sch]
2019-11-12 oscillator PCB
    [opamp_sine_oscillator.kicad_pcb, opamp_sine_oscillator.sch]
2019-11-12 update sensor pcb
    [opamp_sine_oscillator.kicad_pcb]
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2019-11-18 phase shift pcb kicad proto
    [phase_shift_sensor_proto.kicad_pcb, phase_shift_sensor_proto.sch]
2019-11-18 phase shift sensor PCB
    [phase_shift_sensor_proto.kicad_pcb, phase_shift_sensor_proto.sch]
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2019-11-22 kicad schematics for wavetable synth
    [wavetable_mixer.kicad_pcb, wavetable_mixer.sch]
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2019-11-25 simple phase shift sensor
    [phase_shift_sensor_proto_simple.kicad_pcb, phase_shift_sensor_proto_simple.sch]
2019-11-25 phase shift sensor proto - simple
    [phase_shift_sensor_proto_simple.kicad_pcb, phase_shift_sensor_proto_simple.sch]
2019-11-25 sensor PCB update
    [phase_shift_sensor_proto_simple.sch]
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2019-11-25 update schematics
    [phase_shift_sensor_proto_simple.kicad_pcb, phase_shift_sensor_proto_simple.sch]
2019-11-25 update phase shift sensor schematics
    [phase_shift_sensor_proto_simple.kicad_pcb, phase_shift_sensor_proto_simple.sch]
2019-11-26 update sensor schematic
    [phase_shift_sensor_proto_simple.kicad_pcb, phase_shift_sensor_proto_simple.sch]
2019-11-26 update phase shift sensor prototype PCB
    [phase_shift_sensor_proto_simple.kicad_pcb]
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2019-11-27 update prototype phase sensor board
    [phase_shift_sensor_proto_simple.kicad_pcb, phase_shift_sensor_proto_simple.sch]
2019-11-27 update phase shift sensor prototype PCB - change connector to 5-pin one, with additional ground
    [phase_shift_sensor_proto_simple.kicad_pcb, phase_shift_sensor_proto_simple.sch]
2019-11-27 SMD version of phase shift sensor
    [phase_shift_sensor_smd.kicad_pcb, phase_shift_sensor_smd.sch]
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2019-12-02 sensor board
    [phase_shift_sensor_proto_simple.kicad_pcb, phase_shift_sensor_proto_simple.sch]
2019-12-05 sensor simulation
    [teensy4_pins_layout.xlsx]
2019-12-06 update kicad project
    [phase_shift_sensor_smd.kicad_pcb, phase_shift_sensor_smd.sch, teensy4_pins_layout.xlsx]
2019-12-10 proto pcb - fix 3v3 voltage reg pins
    [phase_shift_sensor_proto_simple.kicad_pcb]
2019-12-10 update sensor pcb - 3v3 regulator
    [phase_shift_sensor_smd.kicad_pcb, phase_shift_sensor_smd.sch]
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2020-02-10 phase shift sensor modelling
    [teensy4_pins_layout.xlsx]
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2020-02-13 sensor board, 3.3V optional double regulators
    [phase_shift_sensor_smd_3v3.kicad_pcb, phase_shift_sensor_smd_3v3.sch]
2020-02-14 phase shift sensor - new
    [phase_shift_sensor_smd_3v3.kicad_pcb, phase_shift_sensor_smd_3v3.sch, teensy4_pins_layout.xlsx]
2020-02-18 oscillator - KiCAD project
    [square_wave_oscillator_3v3.kicad_pcb, square_wave_oscillator_3v3.sch]
2020-02-18 add oscillator gerber files
2020-02-18 analog switch heterodyne KiCad project
    [analog_switch_heterodyne.kicad_pcb, analog_switch_heterodyne.sch]
2020-02-18 update pcb
    [analog_switch_heterodyne.kicad_pcb, square_wave_oscillator_3v3.kicad_pcb]
2020-02-18 heterodyne pcb
    [analog_switch_heterodyne.kicad_pcb, analog_switch_heterodyne.sch]
2020-02-19 analog switch heterodyne PCB and gerber
    [analog_switch_heterodyne.kicad_pcb, analog_switch_heterodyne.sch, teensy4_pins_layout.xlsx]
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2020-02-26 zoom bad point error - sensor sim
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2020-07-21 bcpu16 - rework of 16bit barrel cpu - 18bit instruction - 8 regs
    [bcpu_defs.sv]
2020-07-31 bcpu16 - integrated
    [bcpu16_isa.xlsx]
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2020-09-23 kicad schematics of npn-pnp colpitts oscillator
    [npn_pnp_colpitts_oscillator.kicad_pcb, npn_pnp_colpitts_oscillator.sch]
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2020-10-02 teensy 4 theremin pcbs, initial version
    [teensy41_display_controls.kicad_pcb, teensy41_display_controls.sch, teensy41_main_board.kicad_pcb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]
2020-10-02 main board pcb
    [teensy41_display_controls.kicad_pcb, teensy41_main_board.kicad_pcb, teensy41_main_board.sch]
2020-10-06 main boark kicad
    [teensy41_main_board.kicad_pcb, teensy41_main_board.sch]
2020-10-06 main board
    [teensy41_main_board.kicad_pcb, teensy41_main_board.sch]
2020-10-14 teensy 41 theremin main board and display board rev 0.1
    [teensy41_display_controls.kicad_pcb, teensy41_display_controls.sch, teensy41_main_board.kicad_pcb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]
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2020-10-21 current sensing based oscillator with bandpass filter
2020-10-22 current sensing oscillator - simple
2020-10-23 current sensing pcb - kicad
    [current_sensing_lvds_out_oscillator.kicad_pcb, current_sensing_lvds_out_oscillator.sch]
2020-10-23 current sensing single ended oscillator kicad project
    [current_sensing_single_ended_oscillator.kicad_pcb, current_sensing_single_ended_oscillator.sch]
2020-10-24 current sensting single ended compact pcb
    [current_sensing_single_ended_oscillator_compact.kicad_pcb, current_sensing_single_ended_oscillator_compact.sch]
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2020-10-24 update oscillator pcb
    [current_sensing_single_ended_oscillator_compact.kicad_pcb, current_sensing_single_ended_oscillator_compact.sch]
2020-10-30 update sensor
    [current_sensing_single_ended_oscillator_compact.kicad_pcb, current_sensing_single_ended_oscillator_compact.sch]
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2020-11-08 update PCBs
    [adc_dual_pmod_board.kicad_pcb, adc_dual_pmod_board.sch, teensy41_display_controls.kicad_pcb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]
2020-11-10 cora z7 theremin dual 100MHz ADC pmods board
    [adc_dual_pmod_board.kicad_pcb, adc_dual_pmod_board.sch]
2020-11-11 update ADC board pcb, replace ssop20 footprint
    [adc_dual_pmod_board.kicad_pcb, adc_dual_pmod_board.sch]
2020-11-16 teensy theremin main board, v2
    [teensy41_main_board_v2.kicad_pcb, teensy41_main_board_v2.sch]
2020-12-25 BJT current sensing oscillator kicad project
    [current_sensing_bjt.kicad_pcb, current_sensing_bjt.sch]
2020-12-25 update sensor schematics and model:
    [current_sensing_bjt.kicad_pcb, current_sensing_bjt.sch, teensy41_main_board_v2.kicad_pcb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]
2021-05-18 theremin kicad files
    [theremin_sensor_pll_pmod.kicad_pcb, theremin_sensor_pll_pmod.sch, theremin_z7_lite_main_board.kicad_pcb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]
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2021-05-21 pcbs updated, jlcpcb prod rev 0.1, gerber files
    [theremin_lcd_controls_board.kicad_pcb, theremin_sensor_pll_pmod.kicad_pcb, theremin_z7_lite_main_board.kicad_pcb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]
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2021-06-10 iir lowpass filter - fixed
